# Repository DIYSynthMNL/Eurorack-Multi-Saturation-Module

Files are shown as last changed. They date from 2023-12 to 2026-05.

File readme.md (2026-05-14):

# Synth Distortion / Saturation Module Design

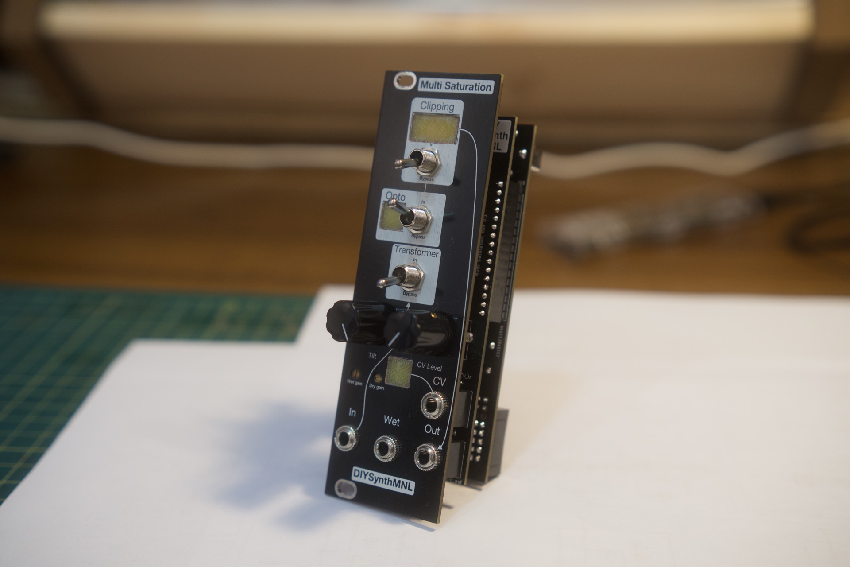
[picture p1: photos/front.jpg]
Multi Saturation assembled


## Revision Summary

- Schematic Revision 0.5 - an easier to read schematic - please note that there are some errors in this. The Eurorack power connector pins are backwards. Use this as a reference for the circuit design.
- Schematic Revision 0.6 - multiboard layout (LATEST - working on circuit revisions)
- PCB Revision 0.1 - revising in progress (working on rev 0.2)

## Some background.

I’m designing a distortion/saturation modular synth module using different methods of distorting audio signals.

This module is a combination of transformer, opto, and clipping distortion/saturation.

## Source of inspiration

Local archived copies of the borrowed-source schematics live in [`references/`](references/) so this repo stays useful if the upstream links die. Originals from [diyrecordingequipment.com](https://www.diyrecordingequipment.com/pages/the-colour-format).

- **CTX Cinemag Transformer Colour mkII** — [local copy](references/DIYRE-CTX-Cinemag-mkII-schematic.pdf) · [upstream](https://cdn.shopify.com/s/files/1/0698/2265/files/CTX_mkII_Schematic.pdf?375)
- **Colourphone (v1.3)** — [local copy](references/DIYRE-Colourphone-schematic-v1.3.pdf) · [upstream](https://cdn.shopify.com/s/files/1/0698/2265/files/XQP_Colourphone_Schematic_1.3.pdf?8973696934571457842)
- **Colourupter (v1.7)** — [local copy](references/DIYRE-Colourupter-schematic-v1.7.pdf) · [upstream](https://cdn.shopify.com/s/files/1/0698/2265/files/XQP_Colourupter_Schematic_1.7.pdf?13355729951948932441)

### DIYRe’s Colour Modules

I got some ideas from DIYRe's Colour modules. DIYRe is a company that produces DIY kits for professional audio recording equipment. Some of their product offerings include recording studio rackmount effects.

[The Colour Format](https://www.diyrecordingequipment.com/pages/the-colour-format)

| Colour Module | What does it do? | What ideas did you get? | Link to page | Schematic |
| --- | --- | --- | --- | --- |
| CTX Transformer Colour | A transformer saturation module with a discrete opamp and a Cinemag audio transformer which has a 1:1 turns ratio. | Non-inverting amp to drive the transformer past what it can handle. Resistor before the transformer that isolates the opamp from the transformer. | https://www.diyrecordingequipment.com/products/ctx-cinemag-transformer-colour-mkii | https://cdn.shopify.com/s/files/1/0698/2265/files/CTX_mkII_Schematic.pdf?375 |
| Colourphone | A telephone sound emulator. It uses a bandpass filter and a 1:1 turn ratio audio transformer. | I have a similar transformer which is a 600:600 ohm transformer. Resistor before the transformer that isolates it from the opamp. | https://www.diyrecordingequipment.com/products/colourphone-telephone-distortion-colour | https://cdn.shopify.com/s/files/1/0698/2265/files/XQP_Colourphone_Schematic_1.3.pdf?8973696934571457842 |
| Colourupter | An opto distortion module that is vactrol based. | Using a vactrol and the circuit around it. IC1c and IC1d only. | https://www.diyrecordingequipment.com/products/colourupter | https://cdn.shopify.com/s/files/1/0698/2265/files/XQP_Colourupter_Schematic_1.7.pdf?13355729951948932441 |

### Other sources

- Vactrol wet/dry mix from music thing modular’s spring reverb module
    - [https://www.musicthing.co.uk/Spring-Reverb/](https://www.musicthing.co.uk/Spring-Reverb/)
- Eliot Sound Products [https://sound-au.com](https://sound-au.com/) - is a website full of audio articles that I’ve learned from. Go search for these articles, they’re great!
    - Designing With Op Amps
    - Audio Transformers
    - Soft Clipping

# Circuit Design

- I will update this section soon.

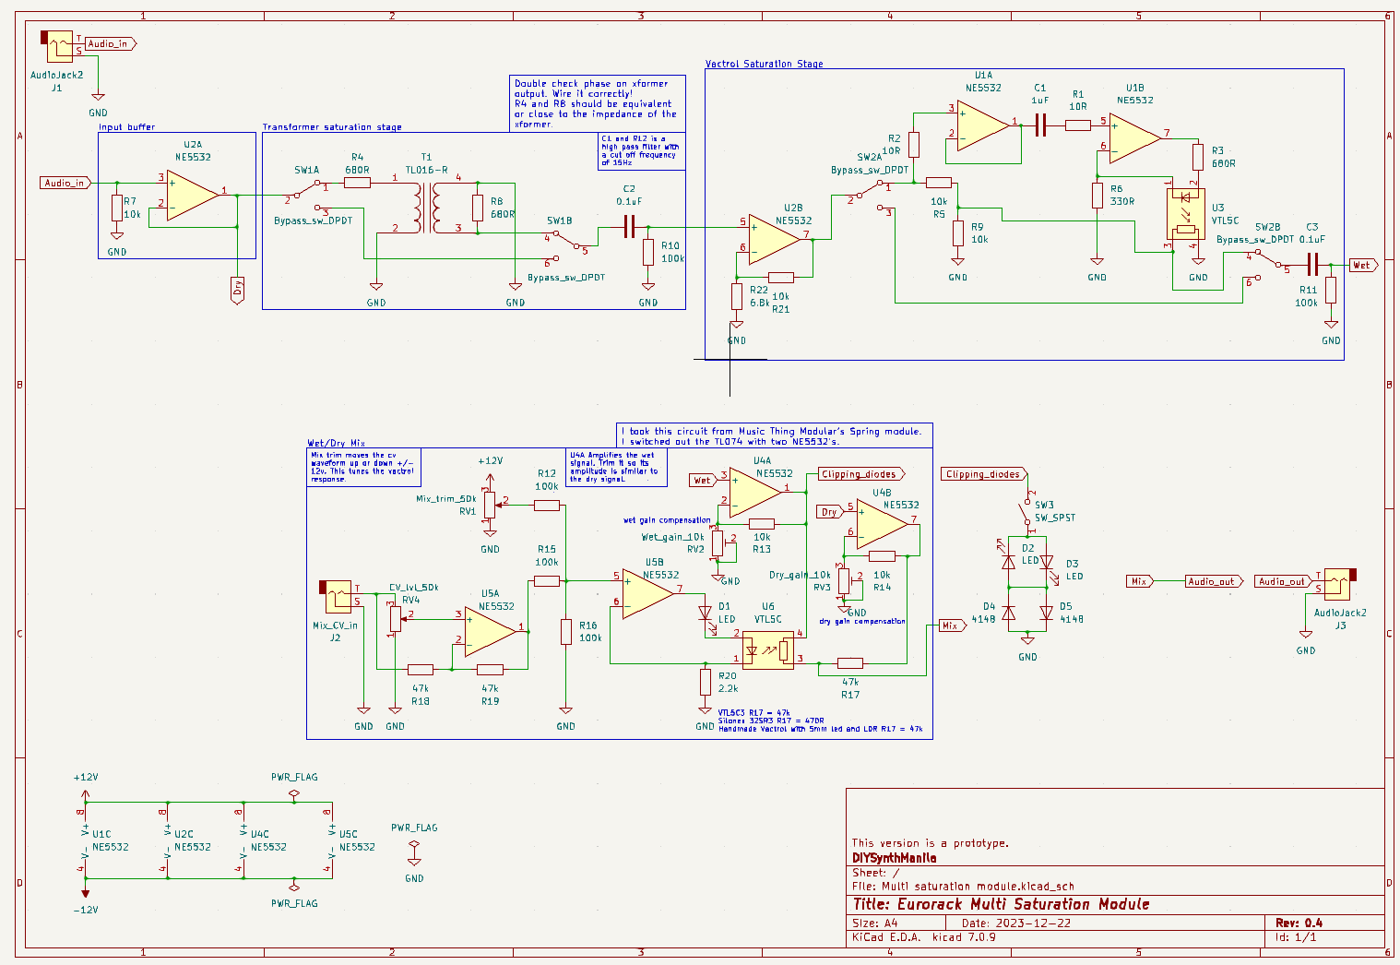
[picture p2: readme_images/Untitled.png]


### Stages

1. Input gain stage (buffer only, see design note below)
    
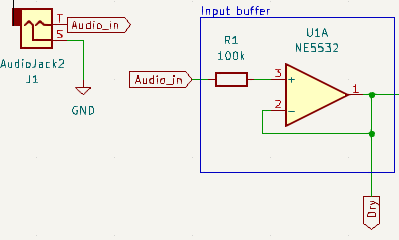
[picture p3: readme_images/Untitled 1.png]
    
    
    We must take into account the headroom of the op amp. The NE5532 can only output 2 volts less than the supply voltage. So for example, your supply voltage would be +/- 12V, your max output would be 10V based on the image below.
    
    
    
    A buffer would suffice as the input stage. It would be nice to give the transformer more voltage but we wouldn’t be able to amplify the 10Vpp input to 12Vpp unless we use a +/- 15V supply. 
    
    I chose to use an NE5532 Op Amp because I believe it can drive outputs higher than TL07x.
    
2. Transformer Saturation
    
    The transformer distortion works by oversaturating the transformer’s core past what it can handle. The transformer I used would normally be used in line audio signals. A 600:600 ohm transformer. We’re using Eurorack voltage which is around 10vpp so that would oversaturate the transformer.
    
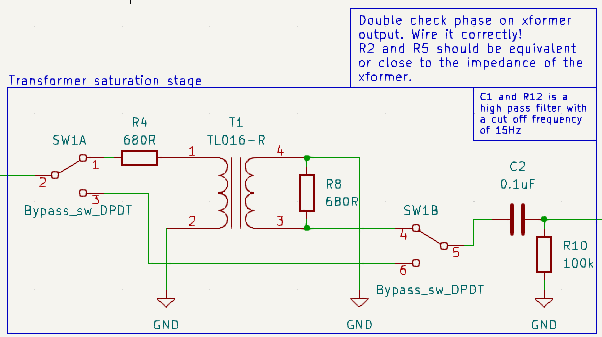
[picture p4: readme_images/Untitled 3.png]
    
    
3. Vactrol Opto Electronic Saturation
    
    The transformer’s output was low, I needed to add a non-inverting op amp with gain to bring the levels back to 10vpp for this stage.
    
    I got this circuit from DIYRe’s Colourupter colour module which uses a Vactrol to clip the signal.
    
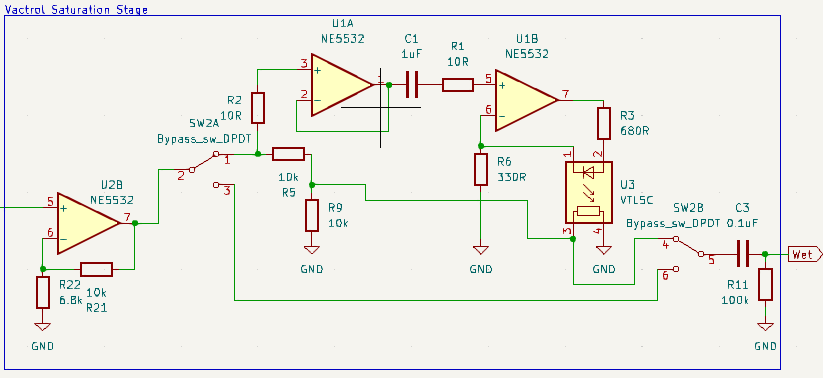
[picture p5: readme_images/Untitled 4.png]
    
    
4. Soft Clipping Diode Saturation
    
    I chose to place these diodes after the wet amplifier. It would be softer if I placed it before the U4A. I chained LEDs to the 1N4148s to get a softer clipping effect. LEDs alone would make saw waves looking like square waves.
    
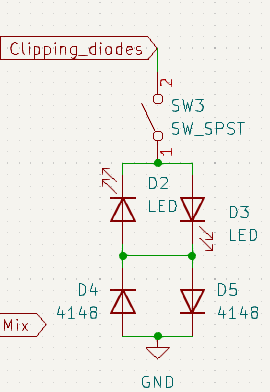
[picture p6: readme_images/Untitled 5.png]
    
    
5. Voltage controlled Vactrol Wet/Dry mix
    
    I used my handmade Vactrol. I made it using a 5mm diffused red LED and a 5mm LDR enclosed with black heat shrink tubing. I crimped the ends so no light would leak in. 47k works for R17 with my Vactrol.
    
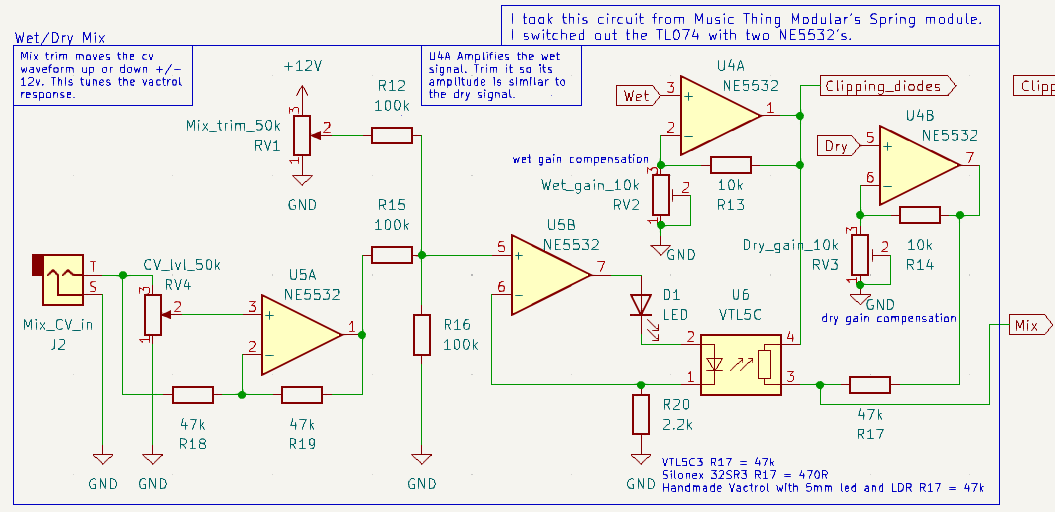
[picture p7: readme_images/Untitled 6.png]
    

## Schematic Revisions:

- Revision 0.2
    - TODO
        - [x]  Replace R5 with trimmer
        - [x]  Test wet/dry mix on breadboard
        - [x]  Input buffer biasing resistor
    - Notes
        - The transformer saturation is very subtle on a mono synth
- Revision 0.3
    - TODO
    - [x]  Add gain trimmer to dry signal at U2B
    - [x]  Scrap the single saturation and add diode clipping and the Colourupter, the transformer alone is too subtle
    - [x]  Test output gain stage
- Revision 0.4
    - [x]  Scrap output auto gain
    - [x]  add opto saturation
    - [x]  add soft clipping diodes
- Revision 0.5
    - [x]  Multiboard layout
- Revision 0.6
    - [ ]  Fix amplitude difference on opto sat stage output.

# PCB Design

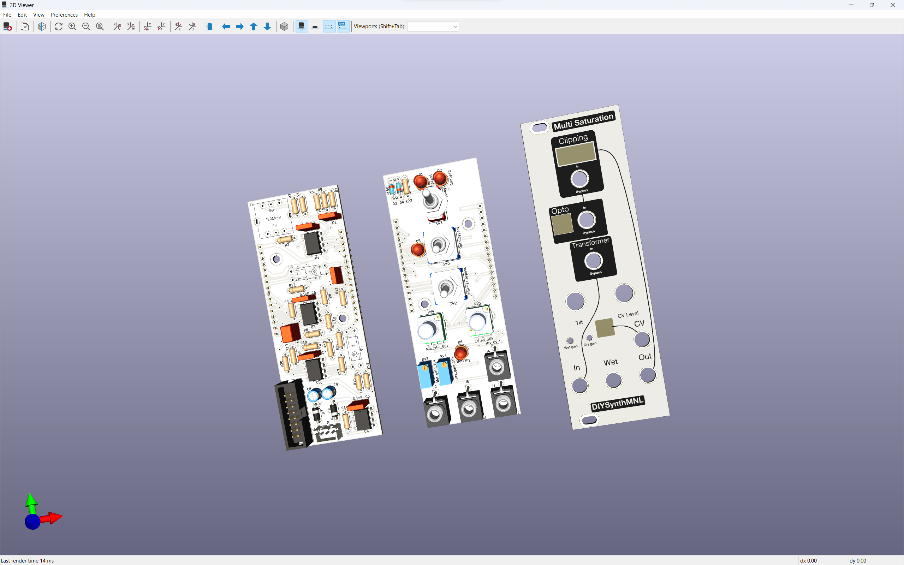
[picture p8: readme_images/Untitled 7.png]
Dec 27, 2023 - Almost satisfied with the board design, rev0.1


Dec 27, 2023 - Almost satisfied  with the board design, rev0.1

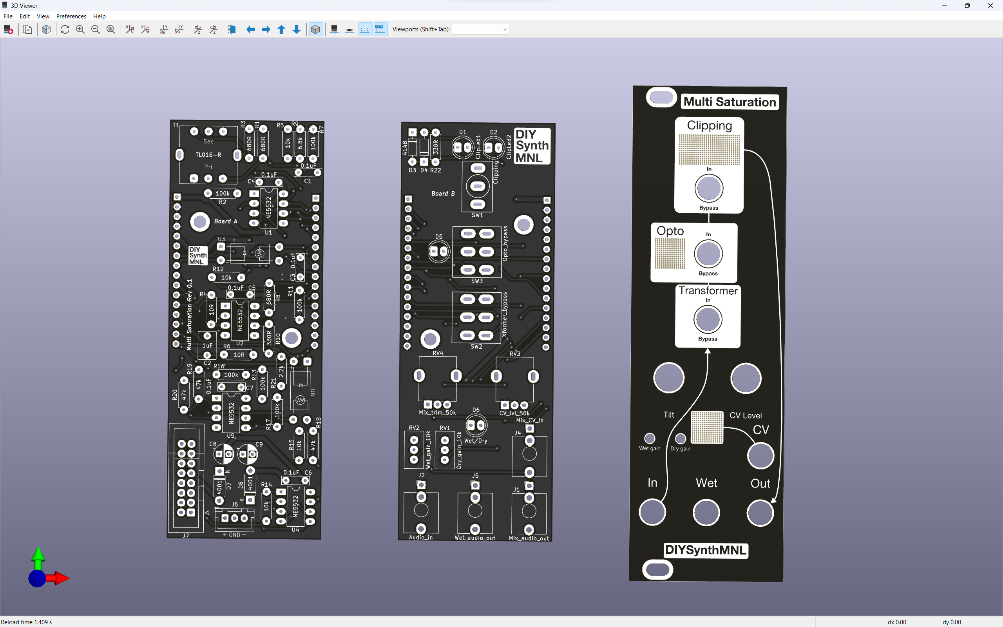
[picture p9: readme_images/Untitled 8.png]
Rev 0.1 in black


Rev 0.1 in black

## PCB revisions:

- Todo for Revision 0.1
    - [x]  Ground plane vias
    - [x]  Front panel ground plane
    - [x]  Double check hole sizes
        - [x]  Trimmer
    - [x]  Double check via sizes
    - [x]  Round tracks
- Todo for Revision 0.2
    - Front panel
        - [x]  Add keep out zone for led window zone fills for FCU and BCU - I had to Dremel it out for the revision 0.1 front panel board
        - [x]  Enlarge switch holes for Dailywell switches
        - [x]  Enlarge trimmer holes
        - [x]  Change tilt knob silkscreen to “mix”
        - [ ]  Fix amplitude difference on opto sat output. The opto stage attenuates the signal from the transformer too much
- Revision 0.1 Board test notes
    - Voltage tests
        - Power rails after reverse protection diode I used a 1N4007 diode
            - V+ reads about 10V
            - V- reads about 11V
            - I might need to change the reverse protection diodes to Schottkys
    - Music thing modular’s cv wet dry circuit has an optimal input of 0-5V control voltages. If 10Vpp was used, the middle of the cv level pot is zero. Fully clockwise, the cv would be in phase. Fully counter clockwise, the cv is inverted. This is simulated in falstad, the file is included in the falstad folder.
    - Gain trim is finicky. Turning on the Opto would attenuate the signal. Maybe this is caused by the variety of the vactrol, I think not all vactrols are equal. Opto gain/amplitude trim might be required. It might be a simple resistor value change within the circuit.
    - LEDs are not as bright as I want them.

## Circuit walkthrough

Three saturation stages in series, each individually bypassable from the front panel, then a CV-controlled wet/dry mix:

```
Audio In ─► U1A buffer ─┬─► [Dry path → wet/dry mixer U4B]
                        │
                        └─► SW1 (Xformer bypass) ─► [TL016 transformer, 680Ω matching, HPF 15Hz]
                                                  ─► U1B buffer ─► transformer-saturated signal
                                                                     │
                                                                     ▼
                                                  SW2 (Opto bypass) ─► U2A buffer ─► C2 (1µF) ─► U2B inverting amp (gain −68)
                                                                                                    ├─► drives U3 vactrol LED (R10 limits)
                                                                                                    └─► AC-coupled out as "Wet"
                                                                                                                                ▼
                                              U4A amp ────────► clipping LEDs + 1N4148 (SW1 on Board B bypasses)
   Dry signal ──► U4B amp ───────────────────┘                                                              │
                                                                                                            ▼
                                                                                  U6 vactrol (CV wet/dry mixer, driven by Mix CV via U5A/U5B)
                                                                                                            ▼
                                                                                                       Mix Audio Out
```

### Three saturation flavors, switchable

**1. Transformer saturation (TL016-R, 600:600Ω).** 680Ω resistors match the transformer's characteristic impedance. Driving the primary hard pushes the magnetic core into non-linearity — classic warm "tape-like" harmonic content (mostly odd harmonics). The 15Hz HPF (C1 + R7) on the secondary removes any DC bias.

**2. Opto-electronic saturation (vactrol, U3).** U2B is a high-gain inverting amp (R8/R6 = 680/10 = **−68× gain**) driving the vactrol's LED. As the signal gets louder, the LED brightens, the LDR resistance drops, more signal shunts to ground — soft compression / saturation. Fast attack/release due to the vactrol's photo response.

**3. Diode soft clipping (Board B).** LEDs (D1, D2) in series with 1N4148s (D3, D4) — asymmetric soft clipping with the LEDs adding ~2V of softness before the 4148s contribute hard clip. Pleasant warmth without harsh square-wave look. SW1 on Board B bypasses.

### Wet/Dry mix (CV-controlled)

Borrowed from Music Thing Modular's Spring reverb topology. Second vactrol (U6) acts as a CV-controlled variable resistor in the mix path. Mix CV input → U5A → U5B → vactrol LED. The Mix Trim pot (RV4, 50K) shifts the CV center point by ±12V so the vactrol's response curve aligns with your CV source (the Music Thing original optimizes for 0–5V CV; this tuning lets it handle ±5V or other ranges).

### Calibration

Three trim pots accessible from the front panel:

**RV2 — Wet gain trim.** Sets U4A's amplification of the wet (saturated) signal. Goal: match the wet signal's amplitude to the dry signal so the mix knob crossfades cleanly.

**RV3 — Dry gain trim.** Sets U4B's amplification of the dry signal. Adjust together with RV2 until at the mix midpoint, the output amplitude doesn't jump as you switch saturation stages on/off.

**RV4 — Mix trim.** Shifts the Mix CV bias up or down ±12V. Adjust until the panel mix pot's full clockwise position gives 100% wet and full counter-clockwise gives 100% dry, with your CV source connected. With no CV connected (or 0V), midpoint should give 50/50.

Procedure:
1. Patch a steady audio signal (e.g., a sawtooth from a VCO) into Audio In.
2. Set all bypass switches to "off" (no saturation) — only the dry path is active.
3. Patch a scope on Mix Audio Out. Note the amplitude.
4. Switch in transformer saturation (SW1). Adjust RV2 (wet gain) so the amplitude is similar to dry.
5. Switch in opto saturation (SW2). If the amplitude drops dramatically here, see [issue #1](https://github.com/DIYSynthMNL/Eurorack-Multi-Saturation-Module/issues) for the known opto-sat fix.
6. With a 0–5V LFO into Mix CV, adjust RV4 (mix trim) so panel mix pot fully clockwise = wet, fully counter-clockwise = dry.

## Build status

What's ready for builders today, and what's still on the TODO list:

**Production assets** (what you need to actually fabricate and assemble a final unit)

- [x] Schematic — Rev 0.6 ([Single saturation module - Multiboard Schematic - rev0.6.pdf](Schematic%20PDFs/Single%20saturation%20module%20-%20Multiboard%20Schematic%20-%20rev0.6.pdf))
- [x] PCB layout — rev 0.1 separated for fab in `kicad/Separate boards/rev 0.1/`; rev 0.2 fixes pending (see PCB revisions in readme)
- [ ] Gerber files for fabrication — none yet
- [x] BOM — [ibom.html](BOMs/ibom.html)
- [x] Final front panel (SVG/PDF for fab) — [MultiSaturation_FPANEL_FOR_KICAD_IMPORT.svg](Front%20panel%20graphics/MultiSaturation_FPANEL_FOR_KICAD_IMPORT.svg)
- [x] License — [LICENSE](LICENSE)

**Prototype assets** (for breadboard / perfboard / 3D-printed-panel builds before final PCB)

- [ ] 3D-printed prototype panel STL — none yet

**Documentation**

- [x] Photos of the assembled module — see [photos/](photos/)
- [ ] Demo video — none yet
- [ ] Build / assembly instructions — none yet
- [ ] Calibration / tuning notes — none yet

Want to help fill a gap (build photos, gerbers, an assembly guide)? Open an issue or PR.

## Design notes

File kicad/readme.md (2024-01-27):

# Schematic and Boards
I use KiCad with the help of plugins to make it easier to have multi board stack modules.
## My workflow
Based on this workflow you would understand better the files that are in this folder.
- Create an initial schematic
- Create a multiboard schematic
- Design the boards in one file
- Separate the boards using the KiKit plugin
- Use the PCBWay plugin to automatically send the gerbers for PCB manufacturing

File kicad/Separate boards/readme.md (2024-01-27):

# Separate Boards
Within each pcb manufacturing revision, separate boards are made by using KiKit. Then gerbers are generated inside their respective folders. I used PCBWay and their KiCad plugin that generate gerbers while simultaneously ordering them online.

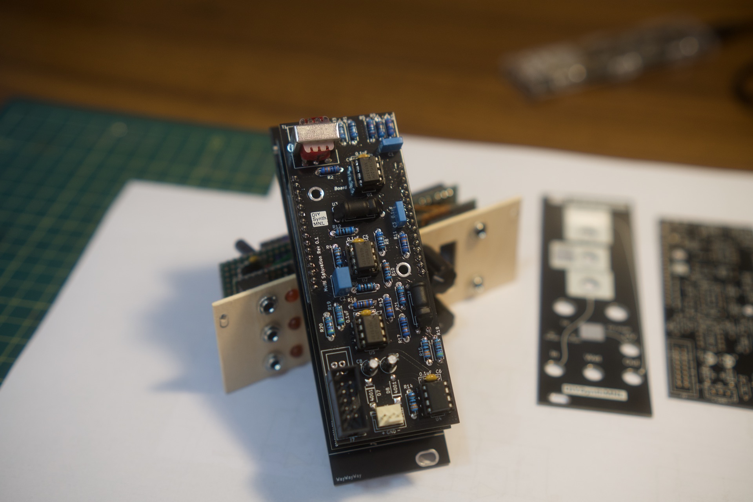
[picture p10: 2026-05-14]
photos/pcb-detail.jpg

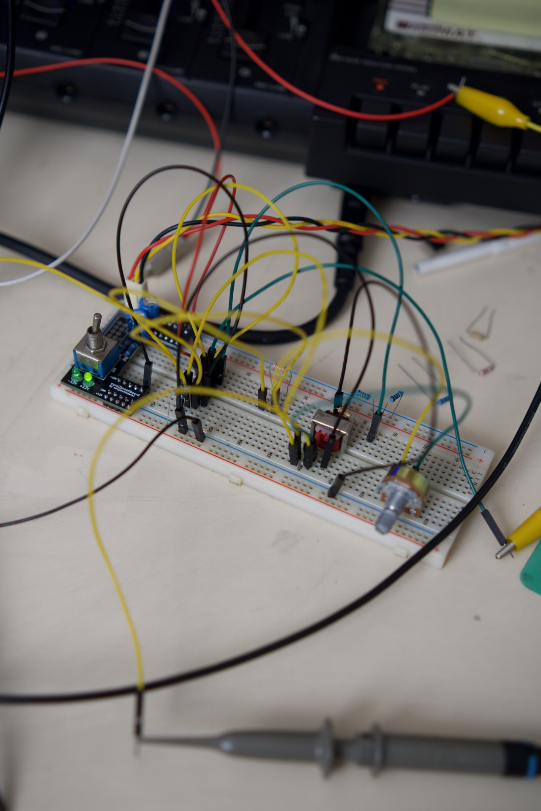
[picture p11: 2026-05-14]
photos/prototyping/proto-01.jpg

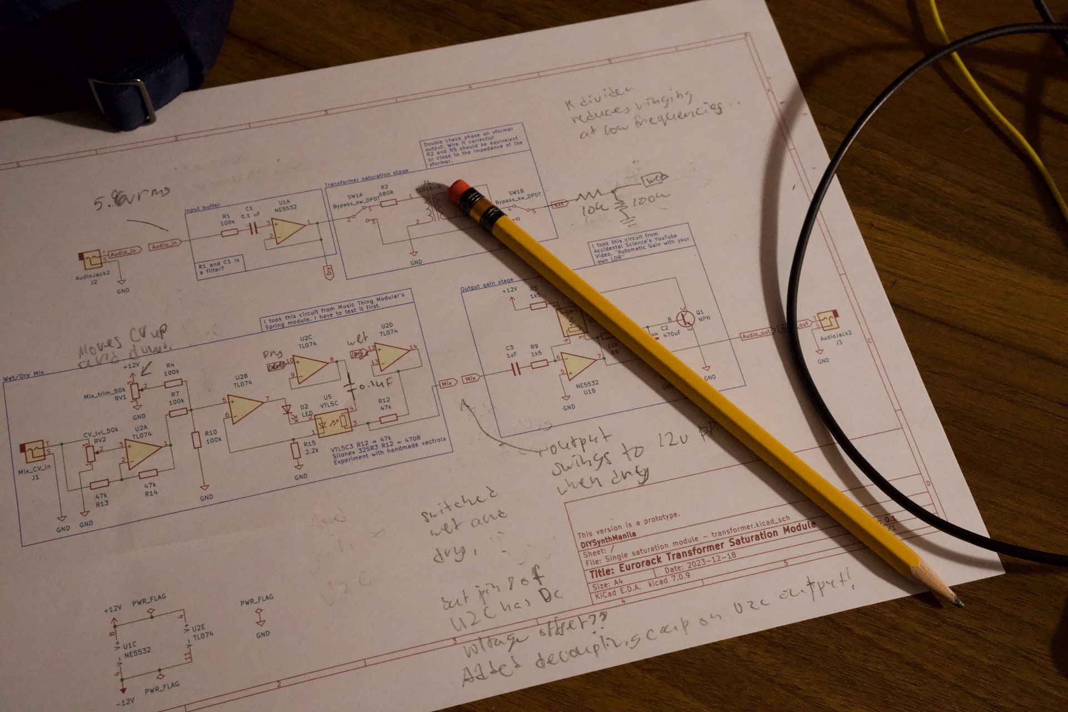
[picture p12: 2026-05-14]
photos/prototyping/proto-12.jpg

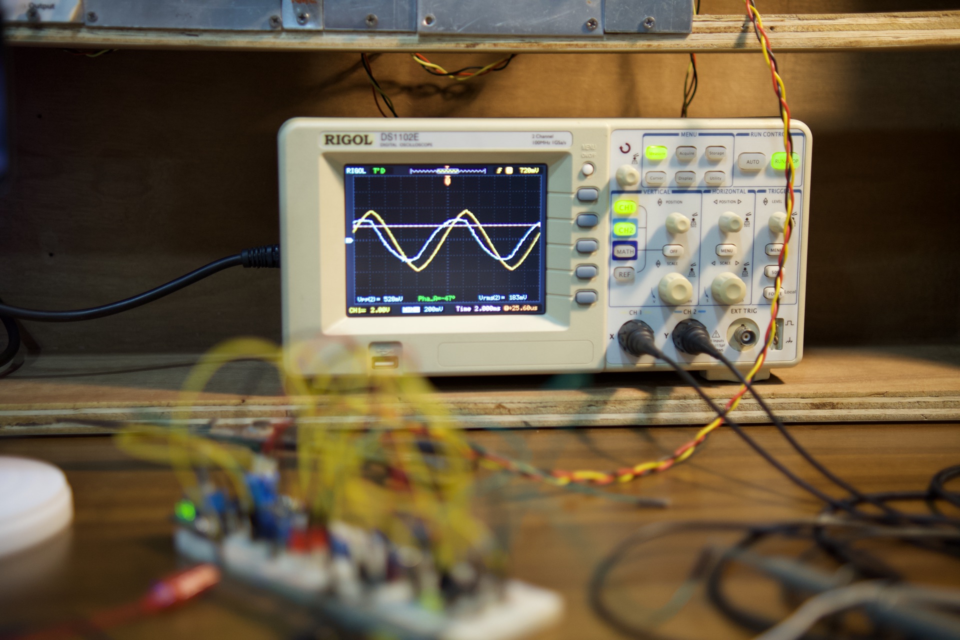
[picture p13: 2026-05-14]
photos/prototyping/proto-08.jpg

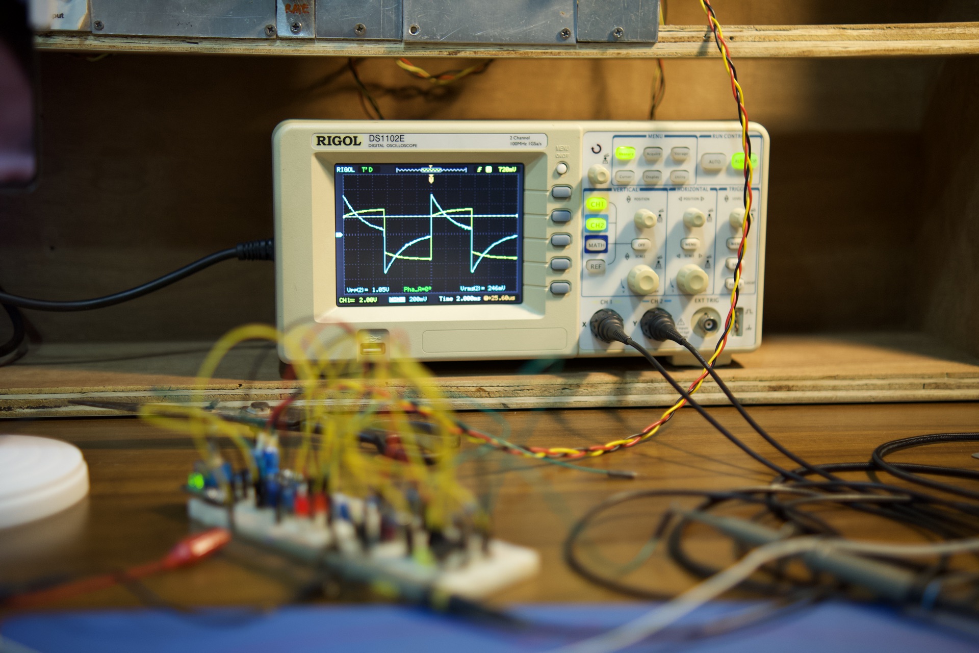
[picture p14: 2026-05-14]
photos/prototyping/proto-07.jpg

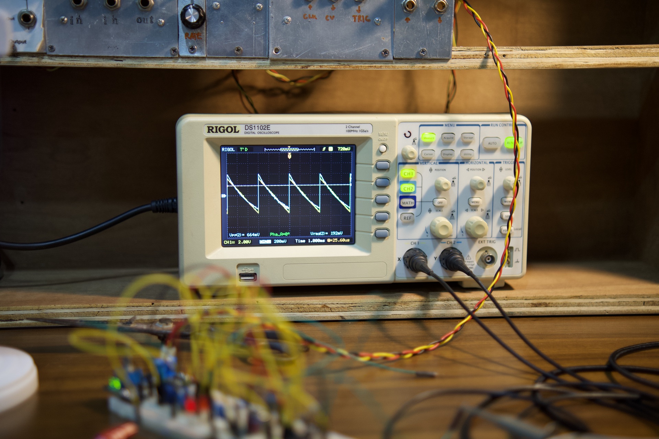
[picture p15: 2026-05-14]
photos/prototyping/proto-09.jpg

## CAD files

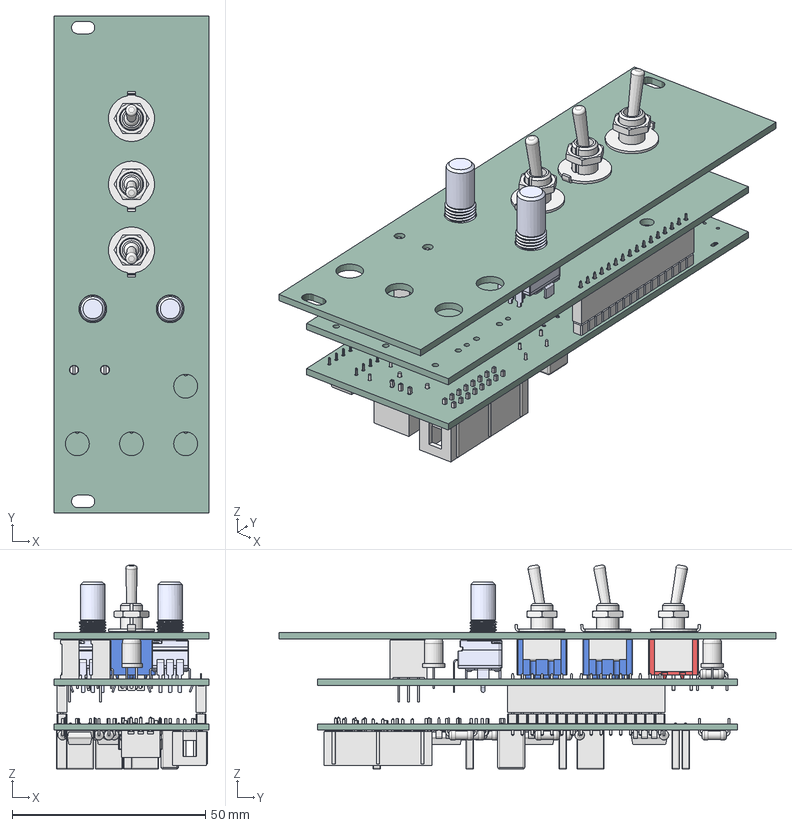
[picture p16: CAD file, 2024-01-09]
3D model/MultiSaturation_3D_Model.FCStd
40.0 x 128.5 x 52.7 mm
Multi saturation module PCB1
Multi saturation module PCB2
Multi saturation module PCB3

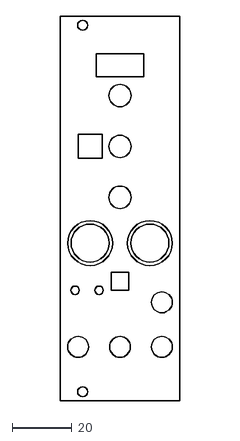
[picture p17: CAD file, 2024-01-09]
Front panel graphics/MultiSaturation_FPANEL.dxf
40.0 x 128.5

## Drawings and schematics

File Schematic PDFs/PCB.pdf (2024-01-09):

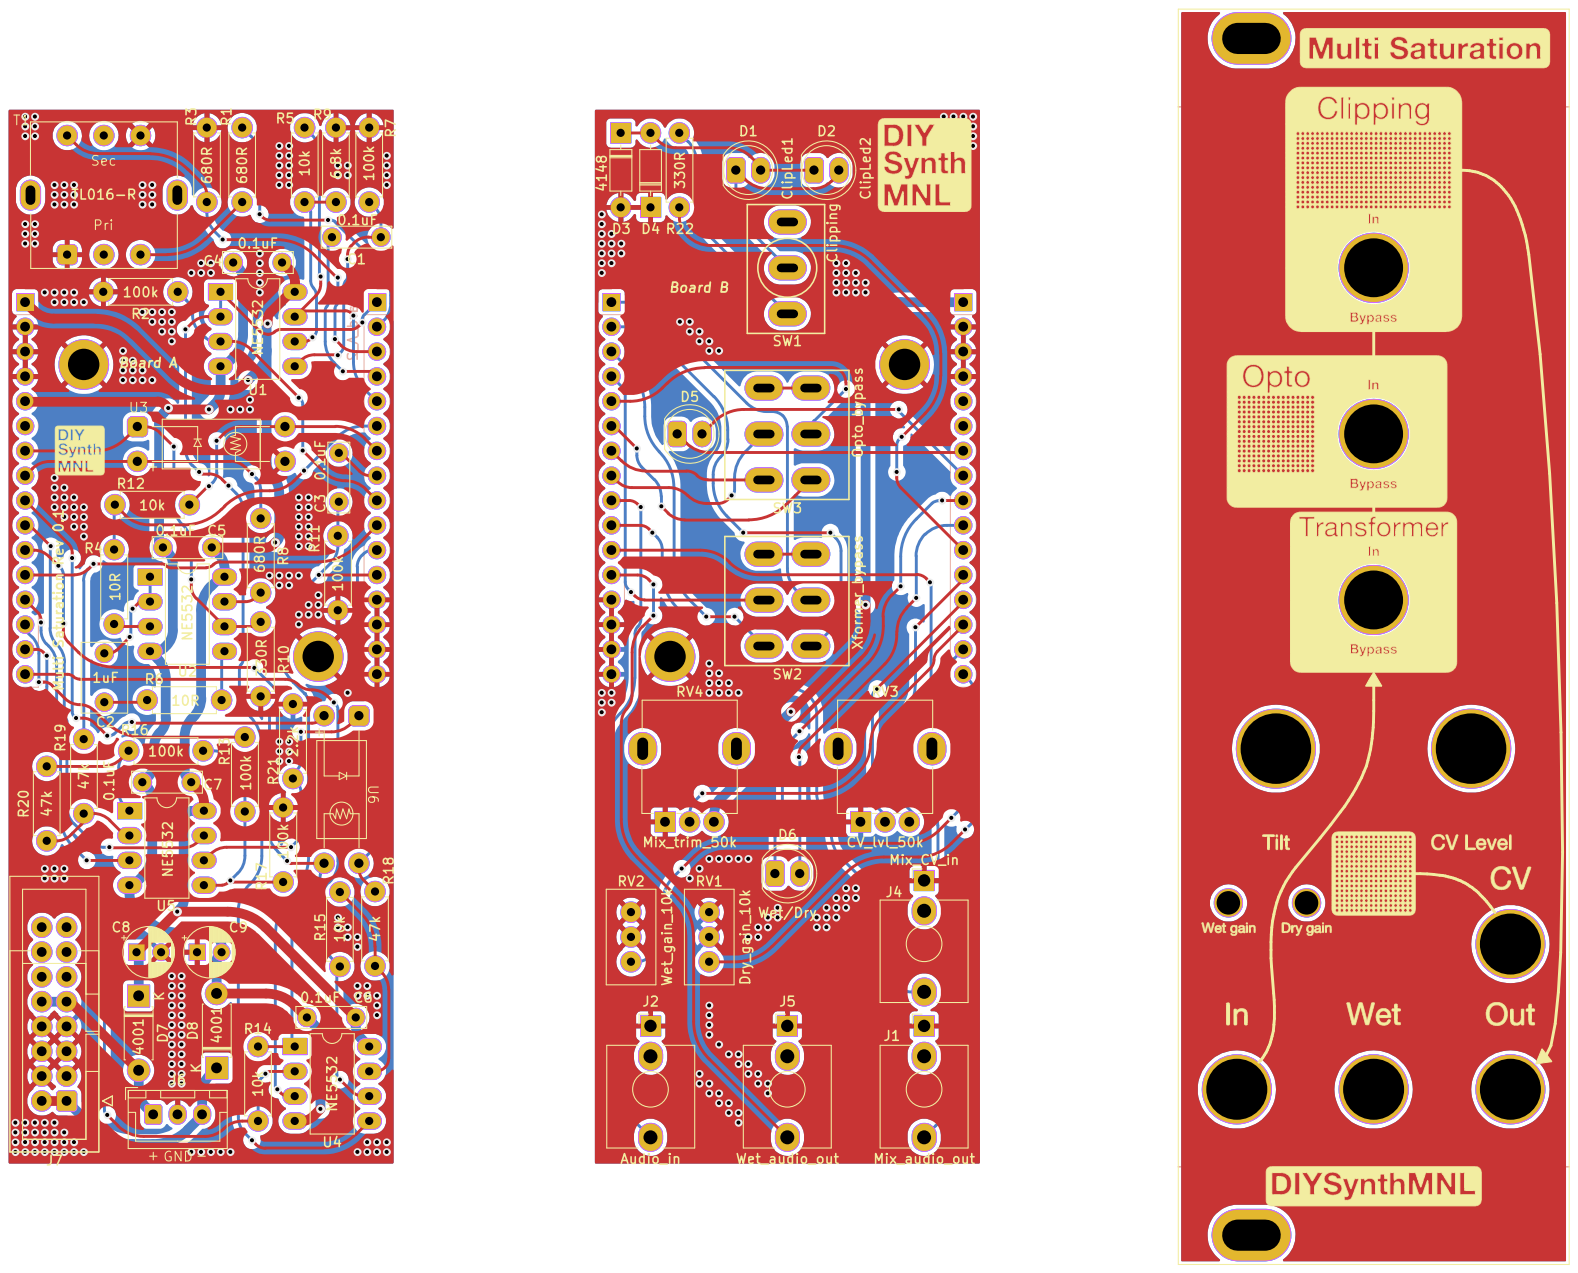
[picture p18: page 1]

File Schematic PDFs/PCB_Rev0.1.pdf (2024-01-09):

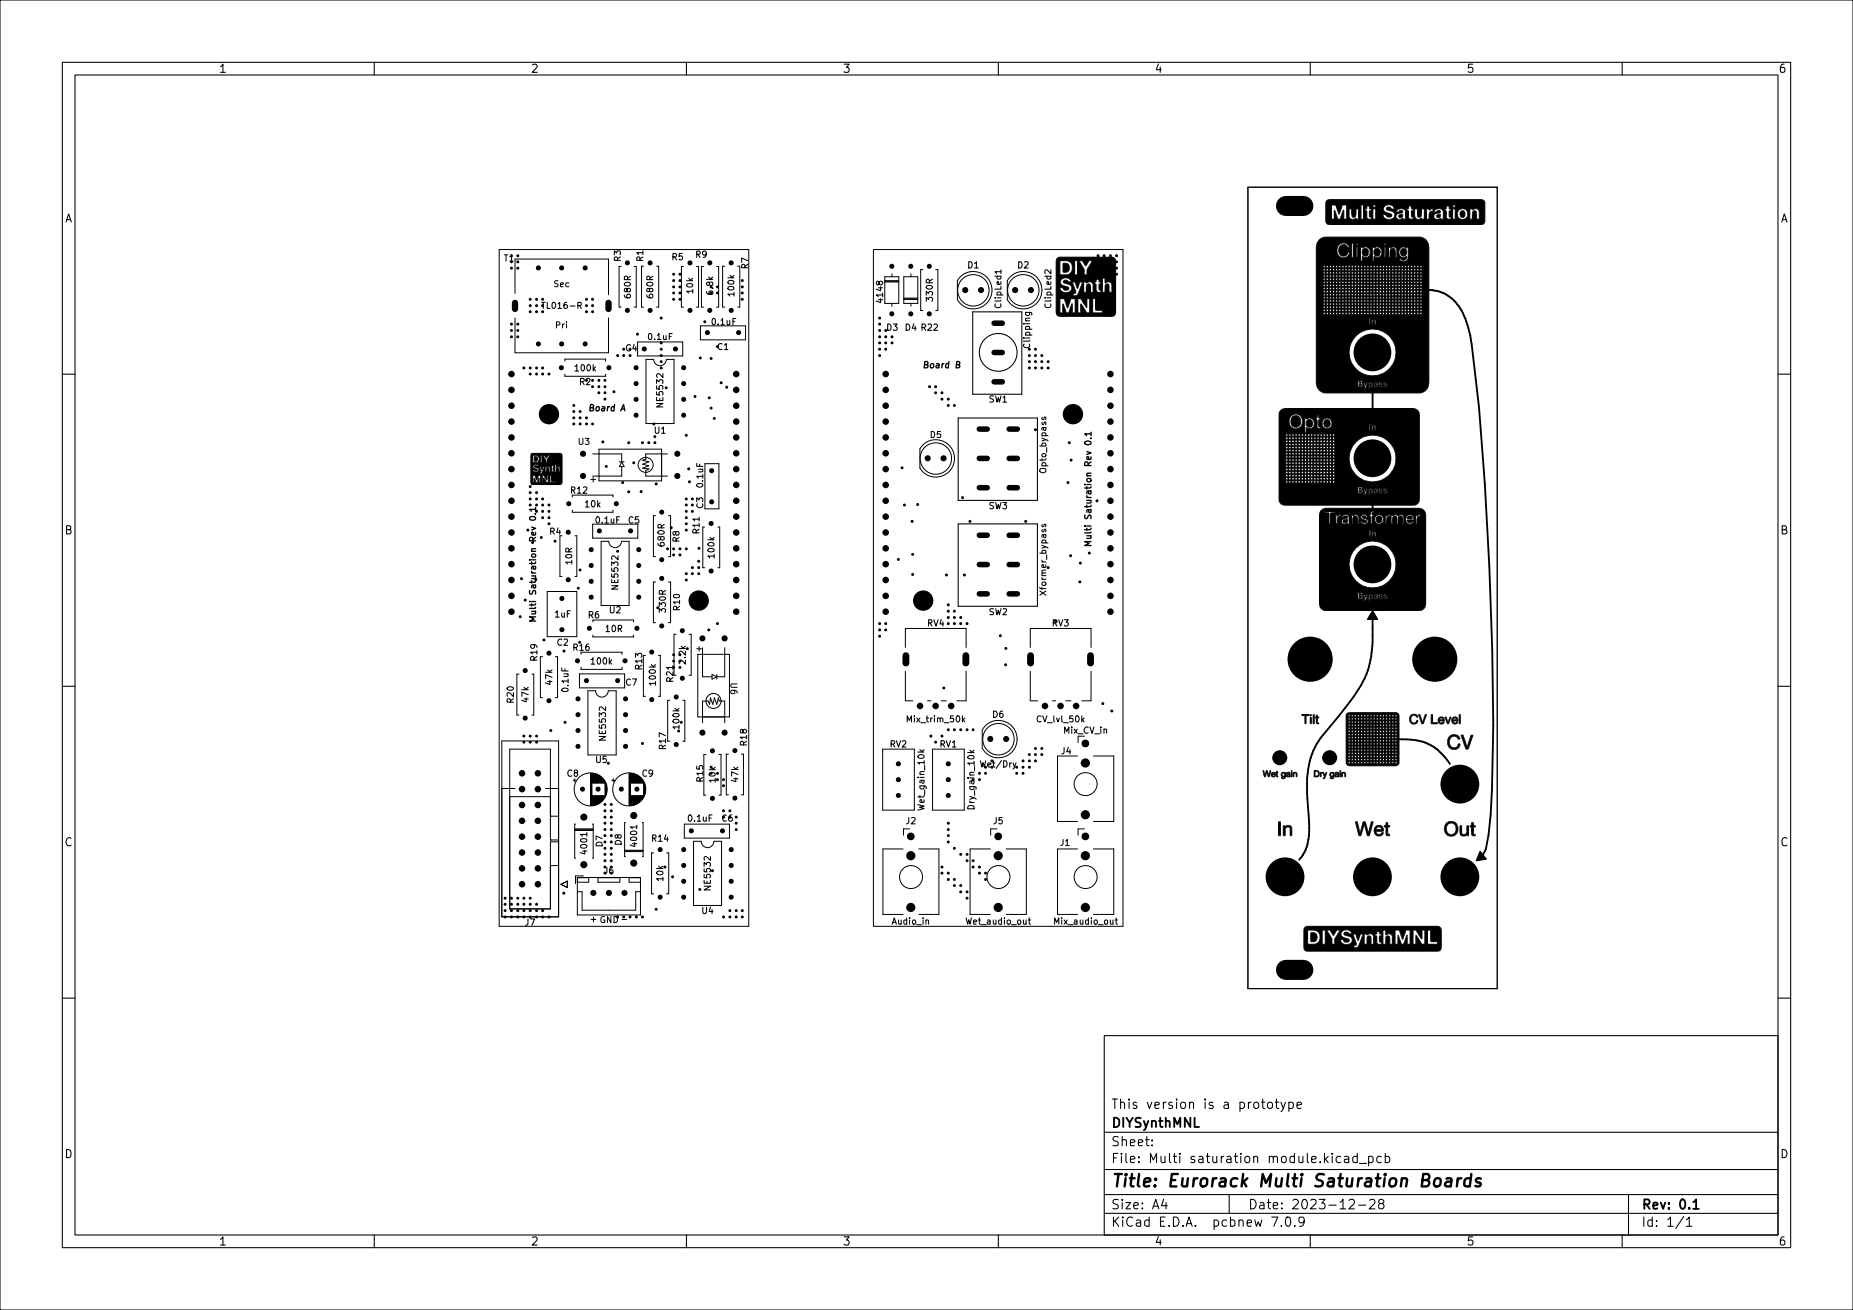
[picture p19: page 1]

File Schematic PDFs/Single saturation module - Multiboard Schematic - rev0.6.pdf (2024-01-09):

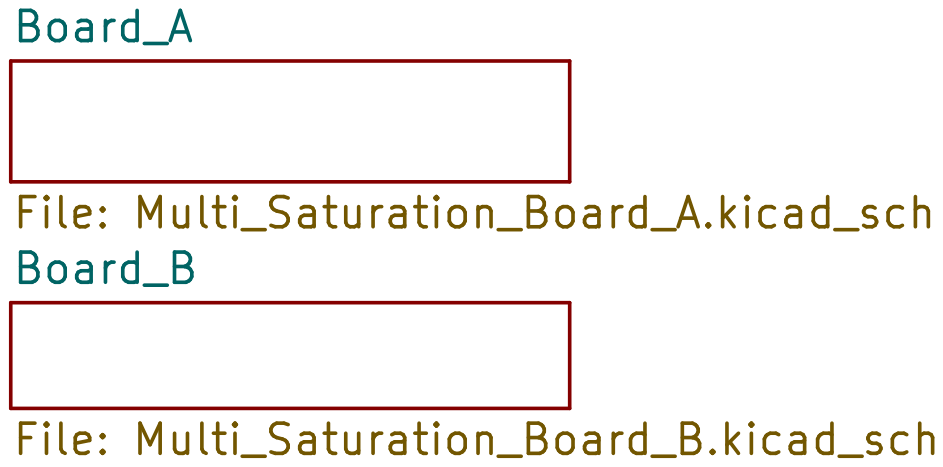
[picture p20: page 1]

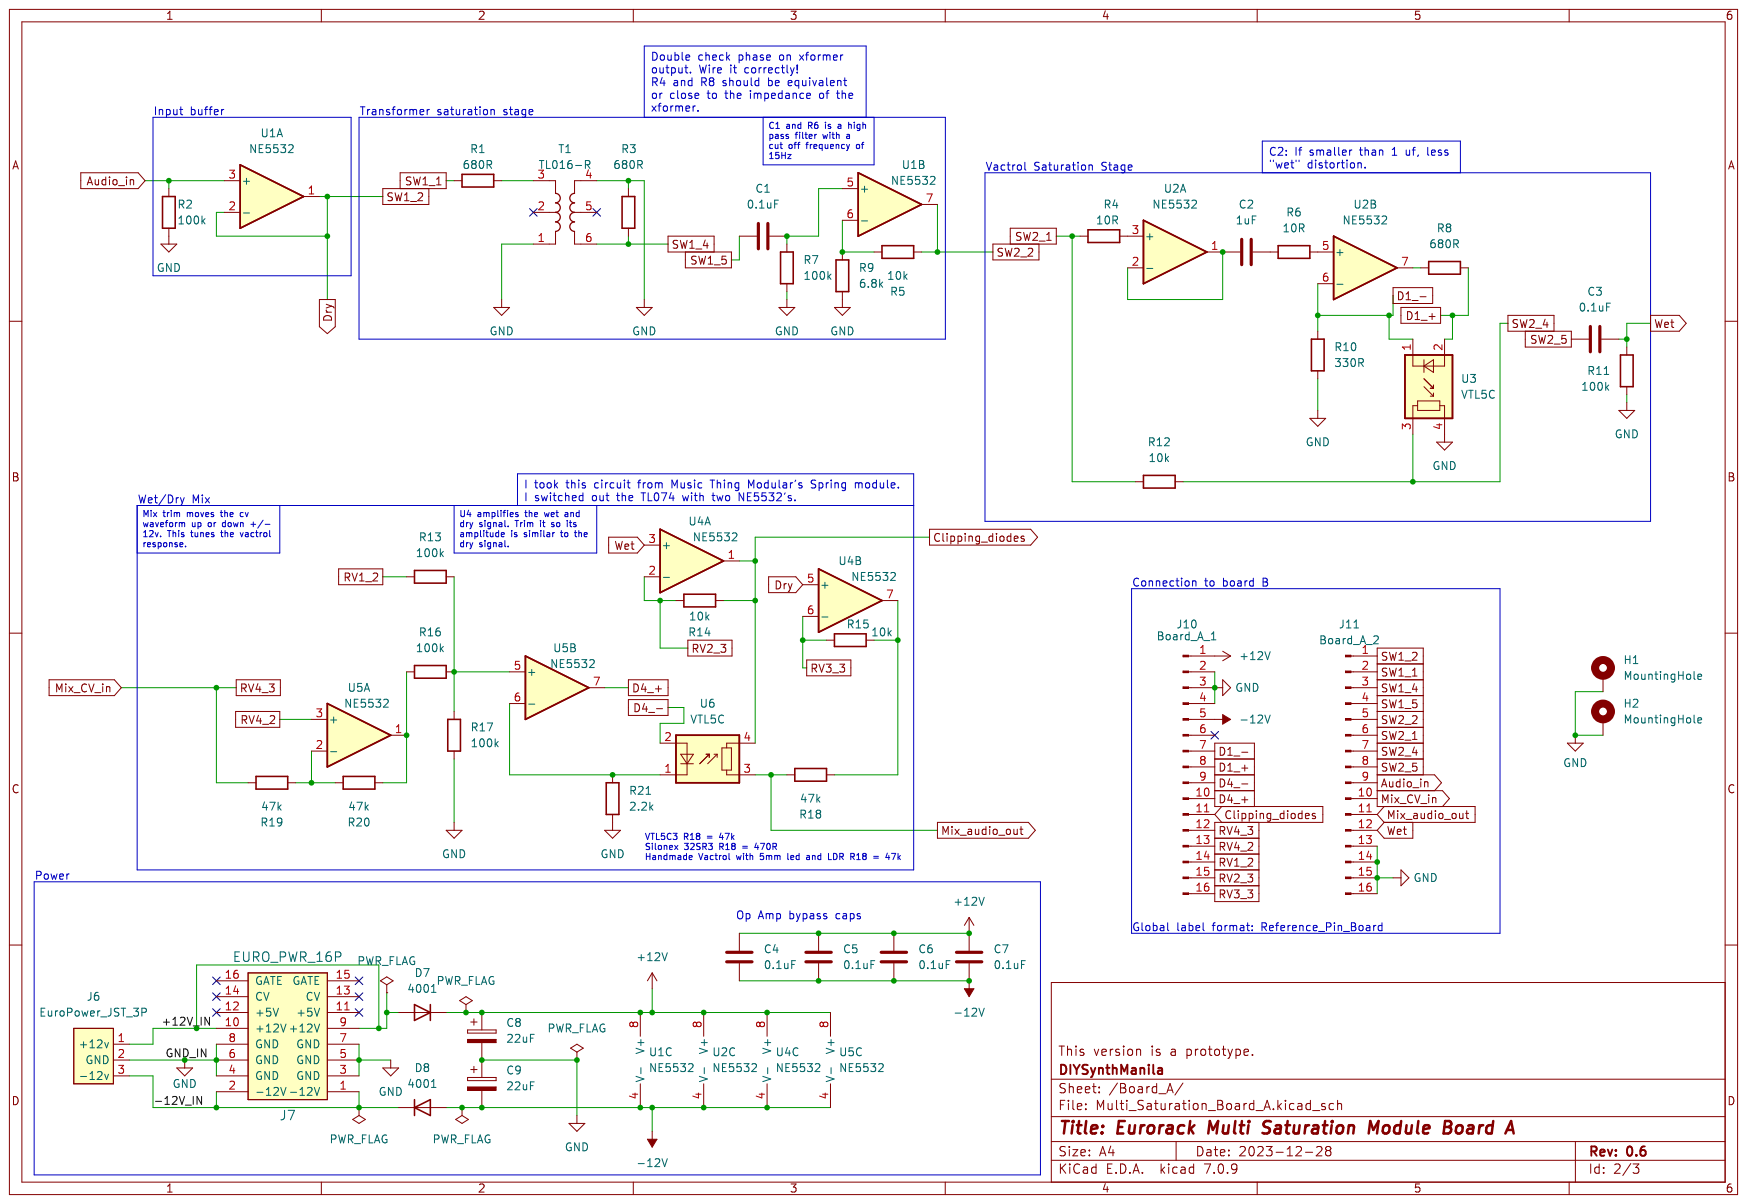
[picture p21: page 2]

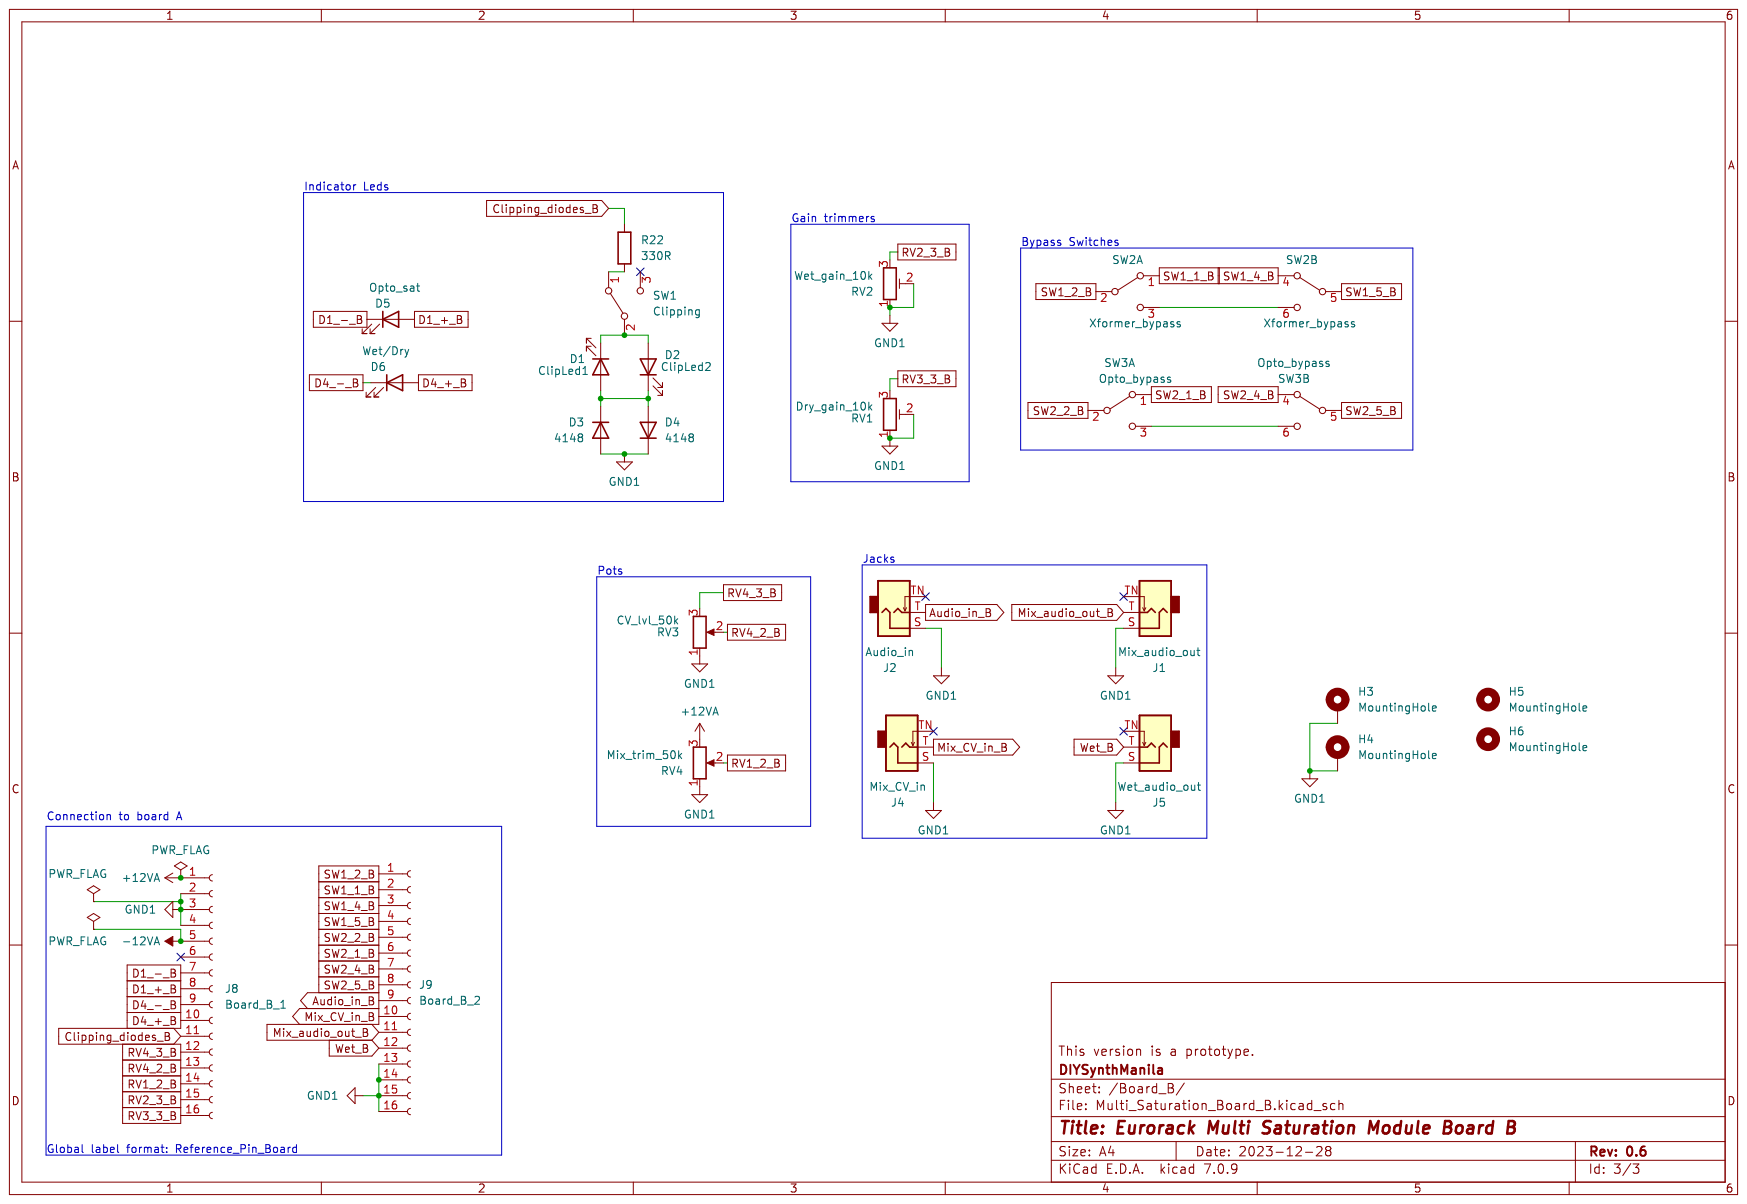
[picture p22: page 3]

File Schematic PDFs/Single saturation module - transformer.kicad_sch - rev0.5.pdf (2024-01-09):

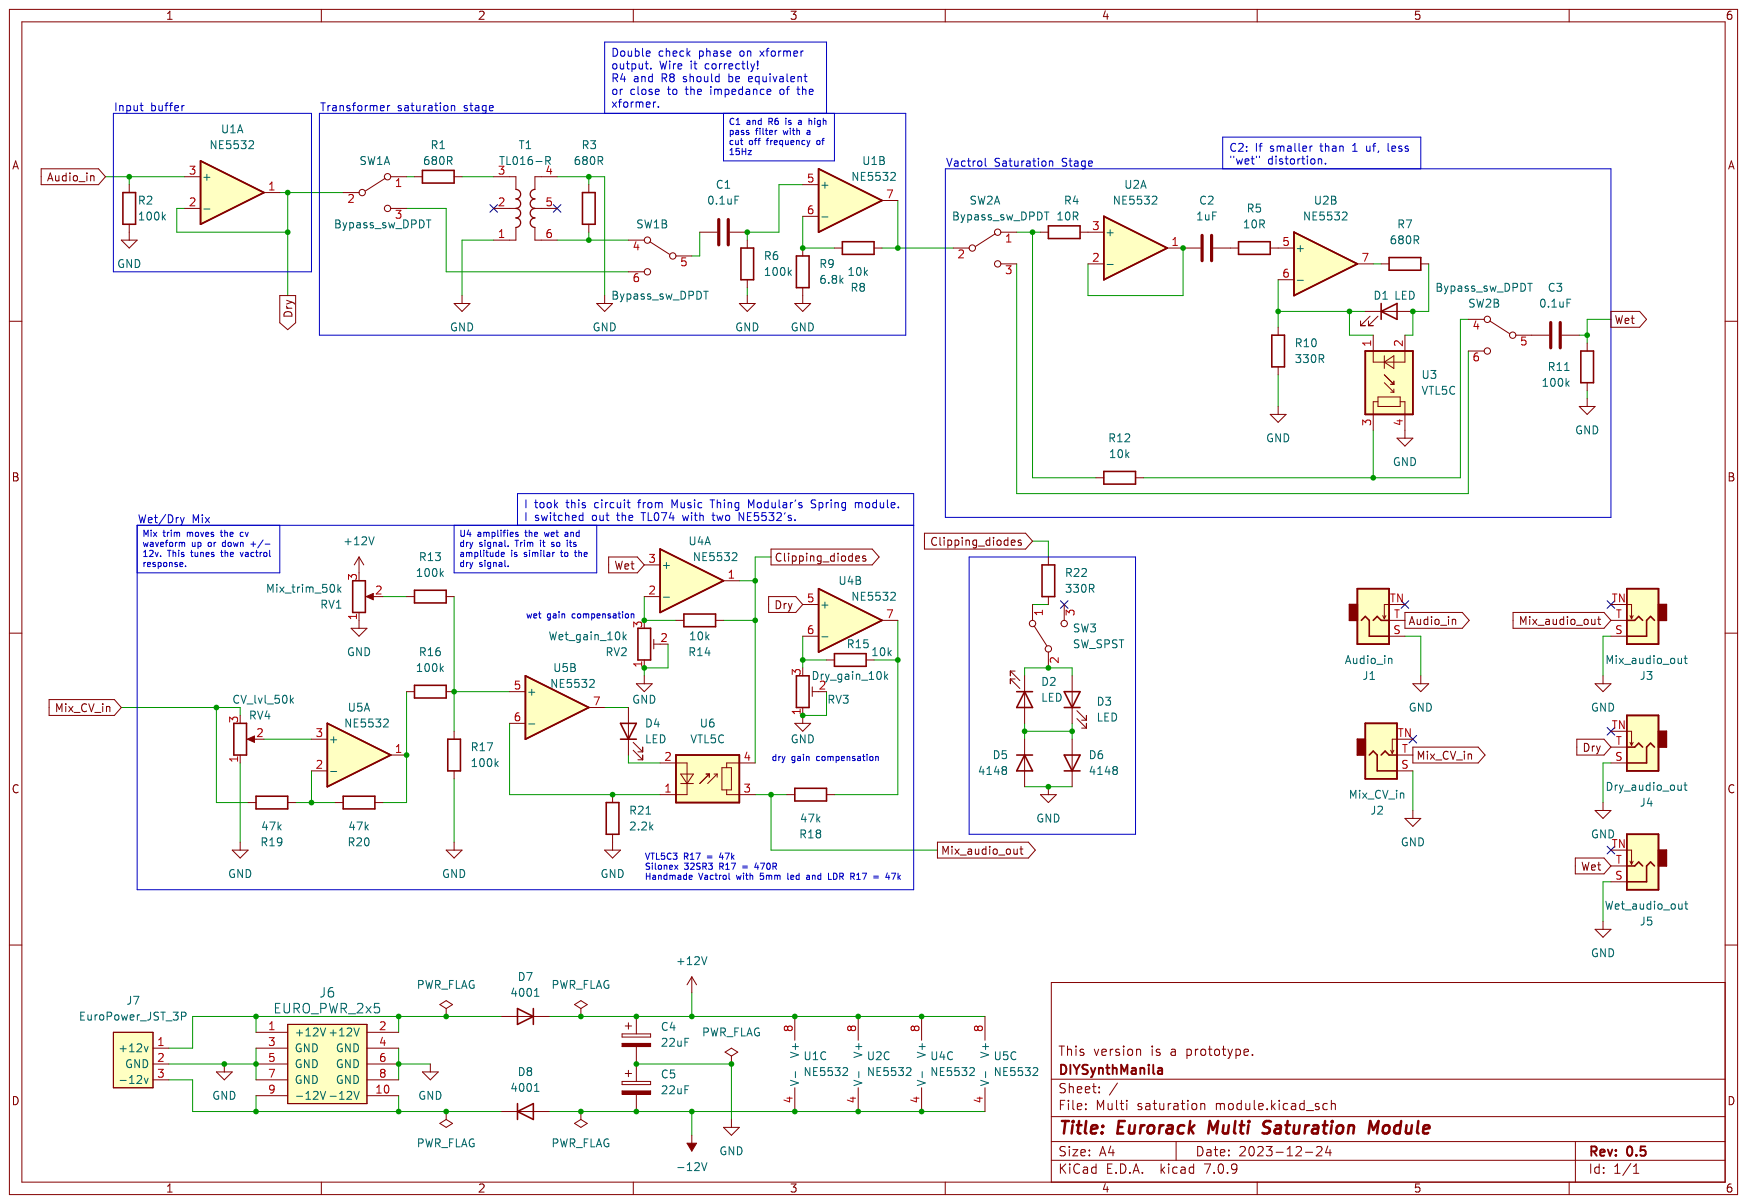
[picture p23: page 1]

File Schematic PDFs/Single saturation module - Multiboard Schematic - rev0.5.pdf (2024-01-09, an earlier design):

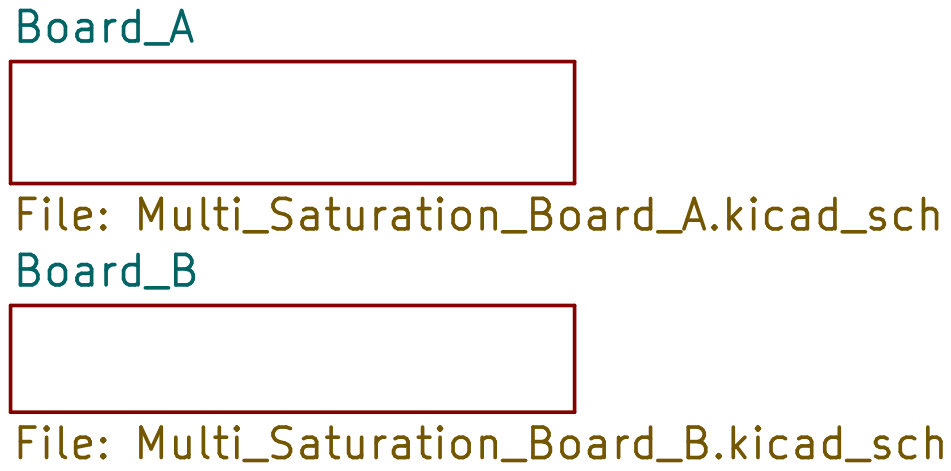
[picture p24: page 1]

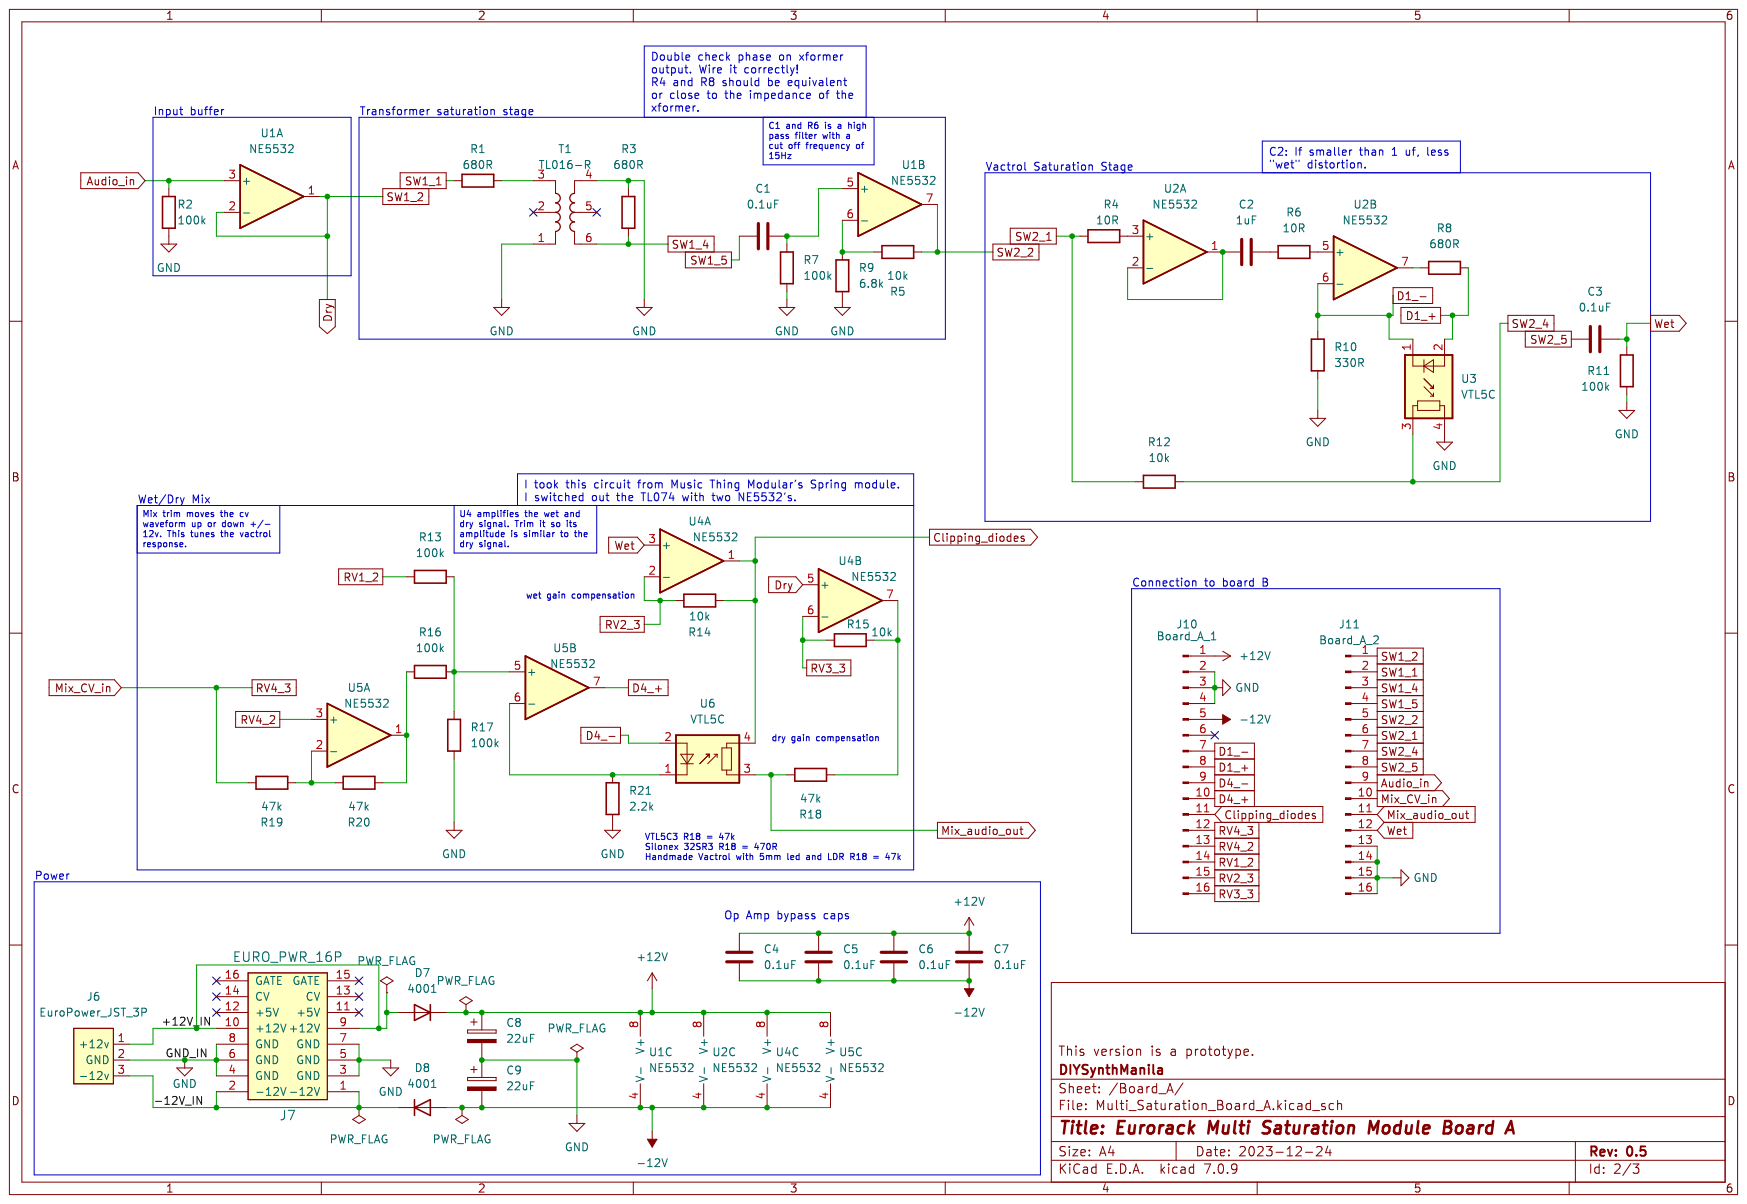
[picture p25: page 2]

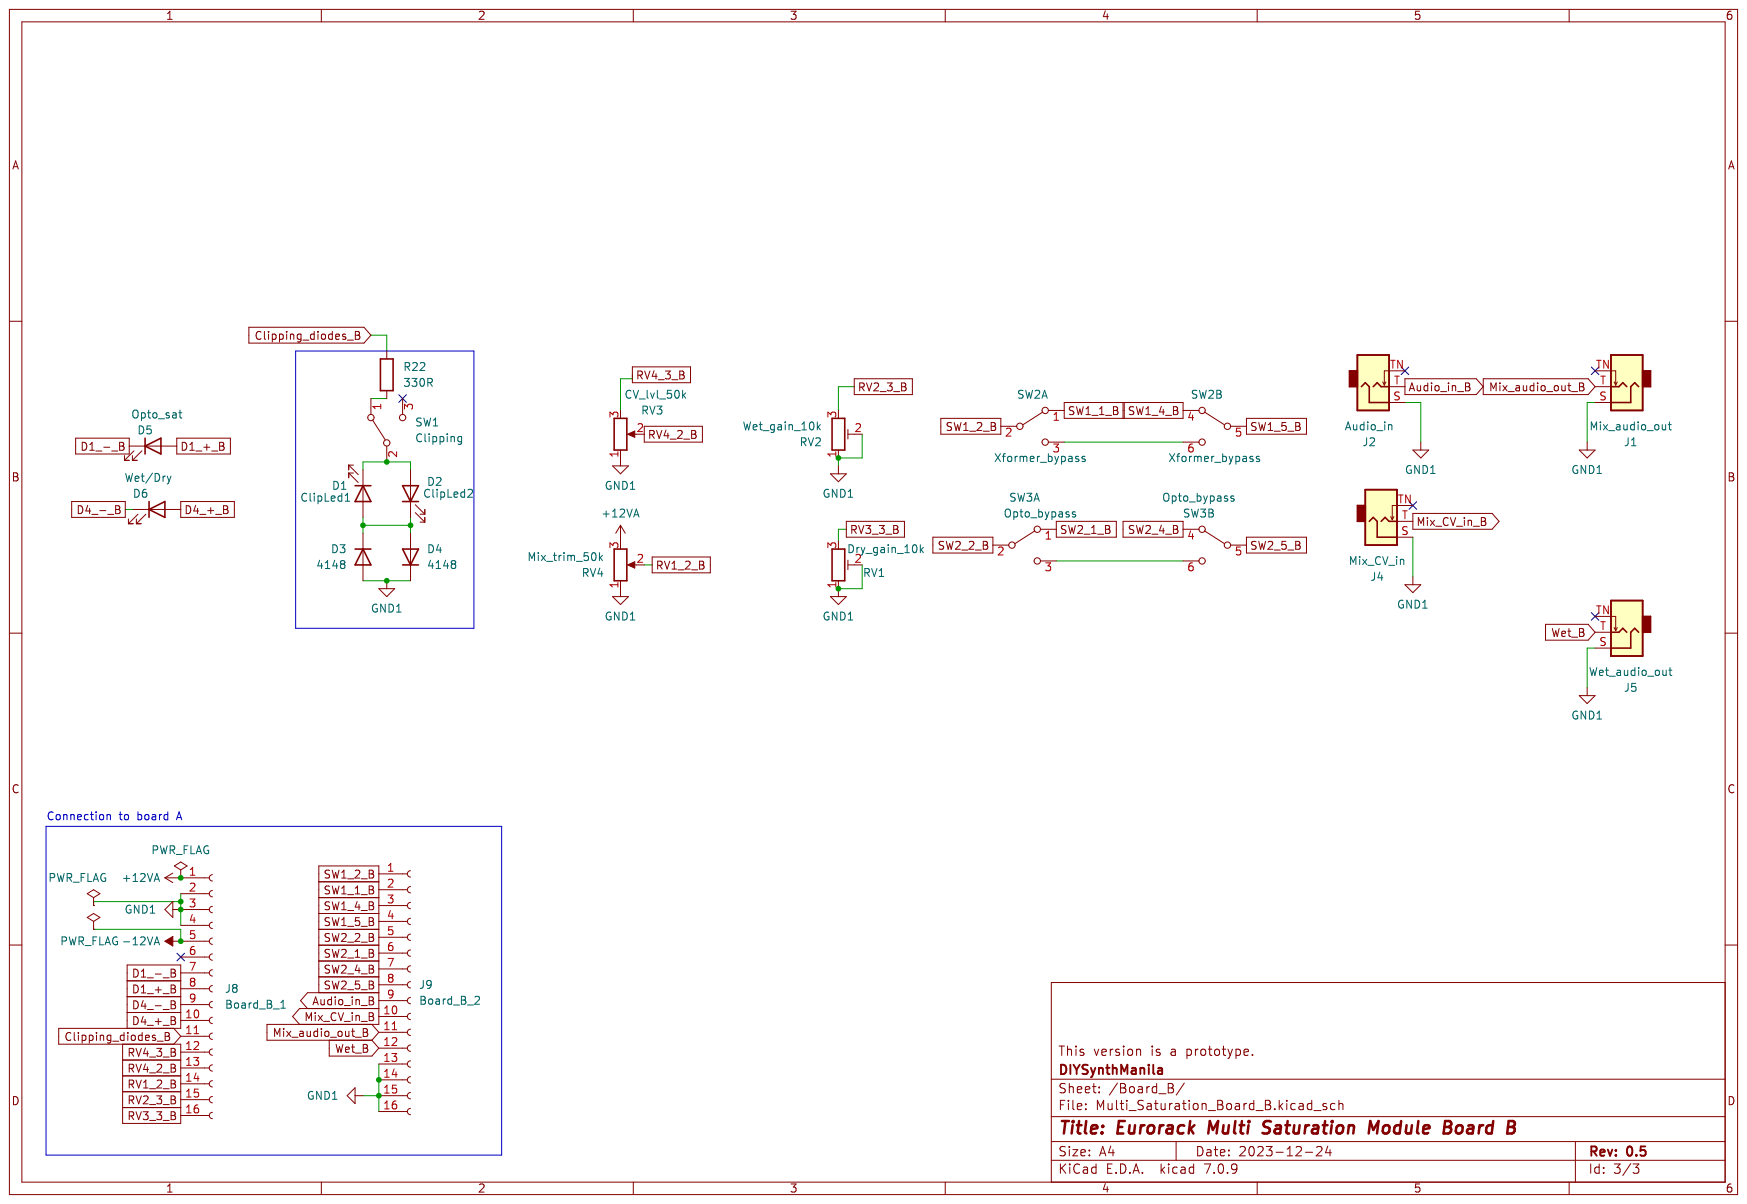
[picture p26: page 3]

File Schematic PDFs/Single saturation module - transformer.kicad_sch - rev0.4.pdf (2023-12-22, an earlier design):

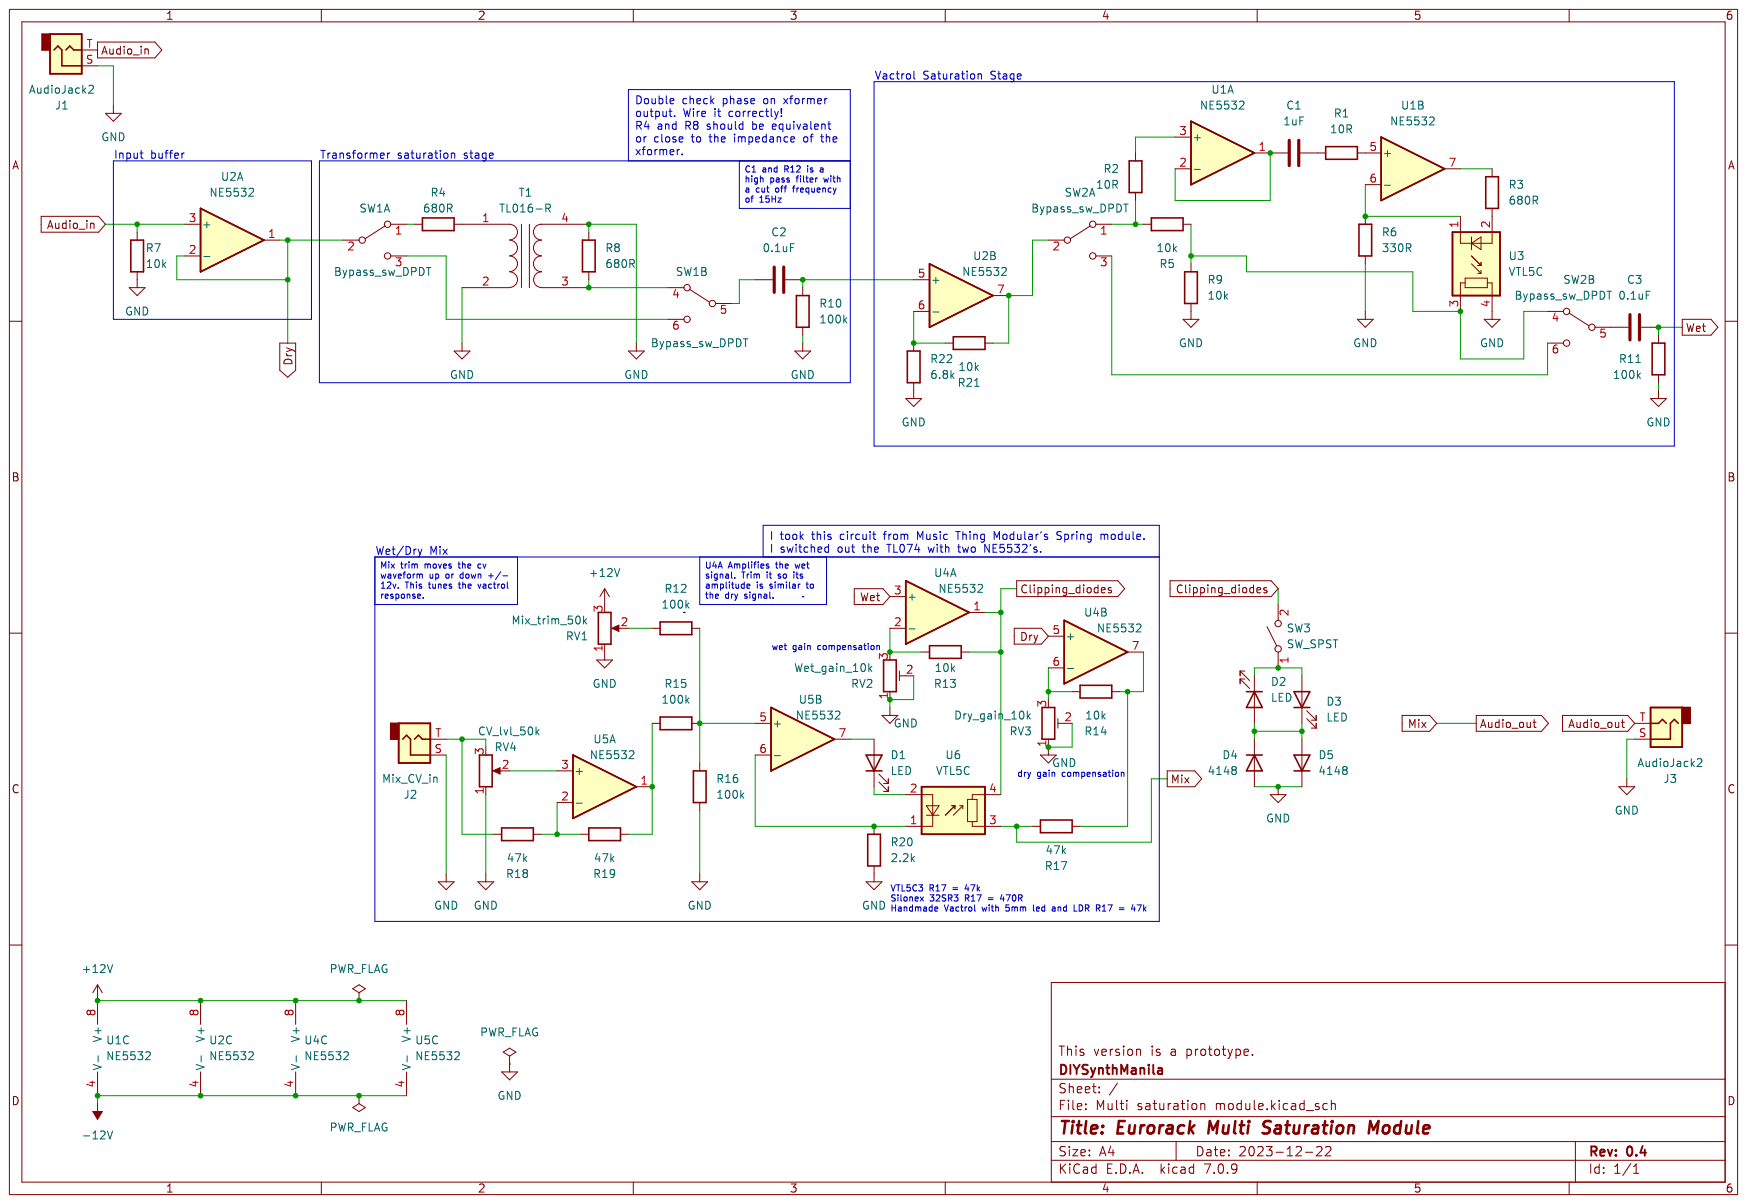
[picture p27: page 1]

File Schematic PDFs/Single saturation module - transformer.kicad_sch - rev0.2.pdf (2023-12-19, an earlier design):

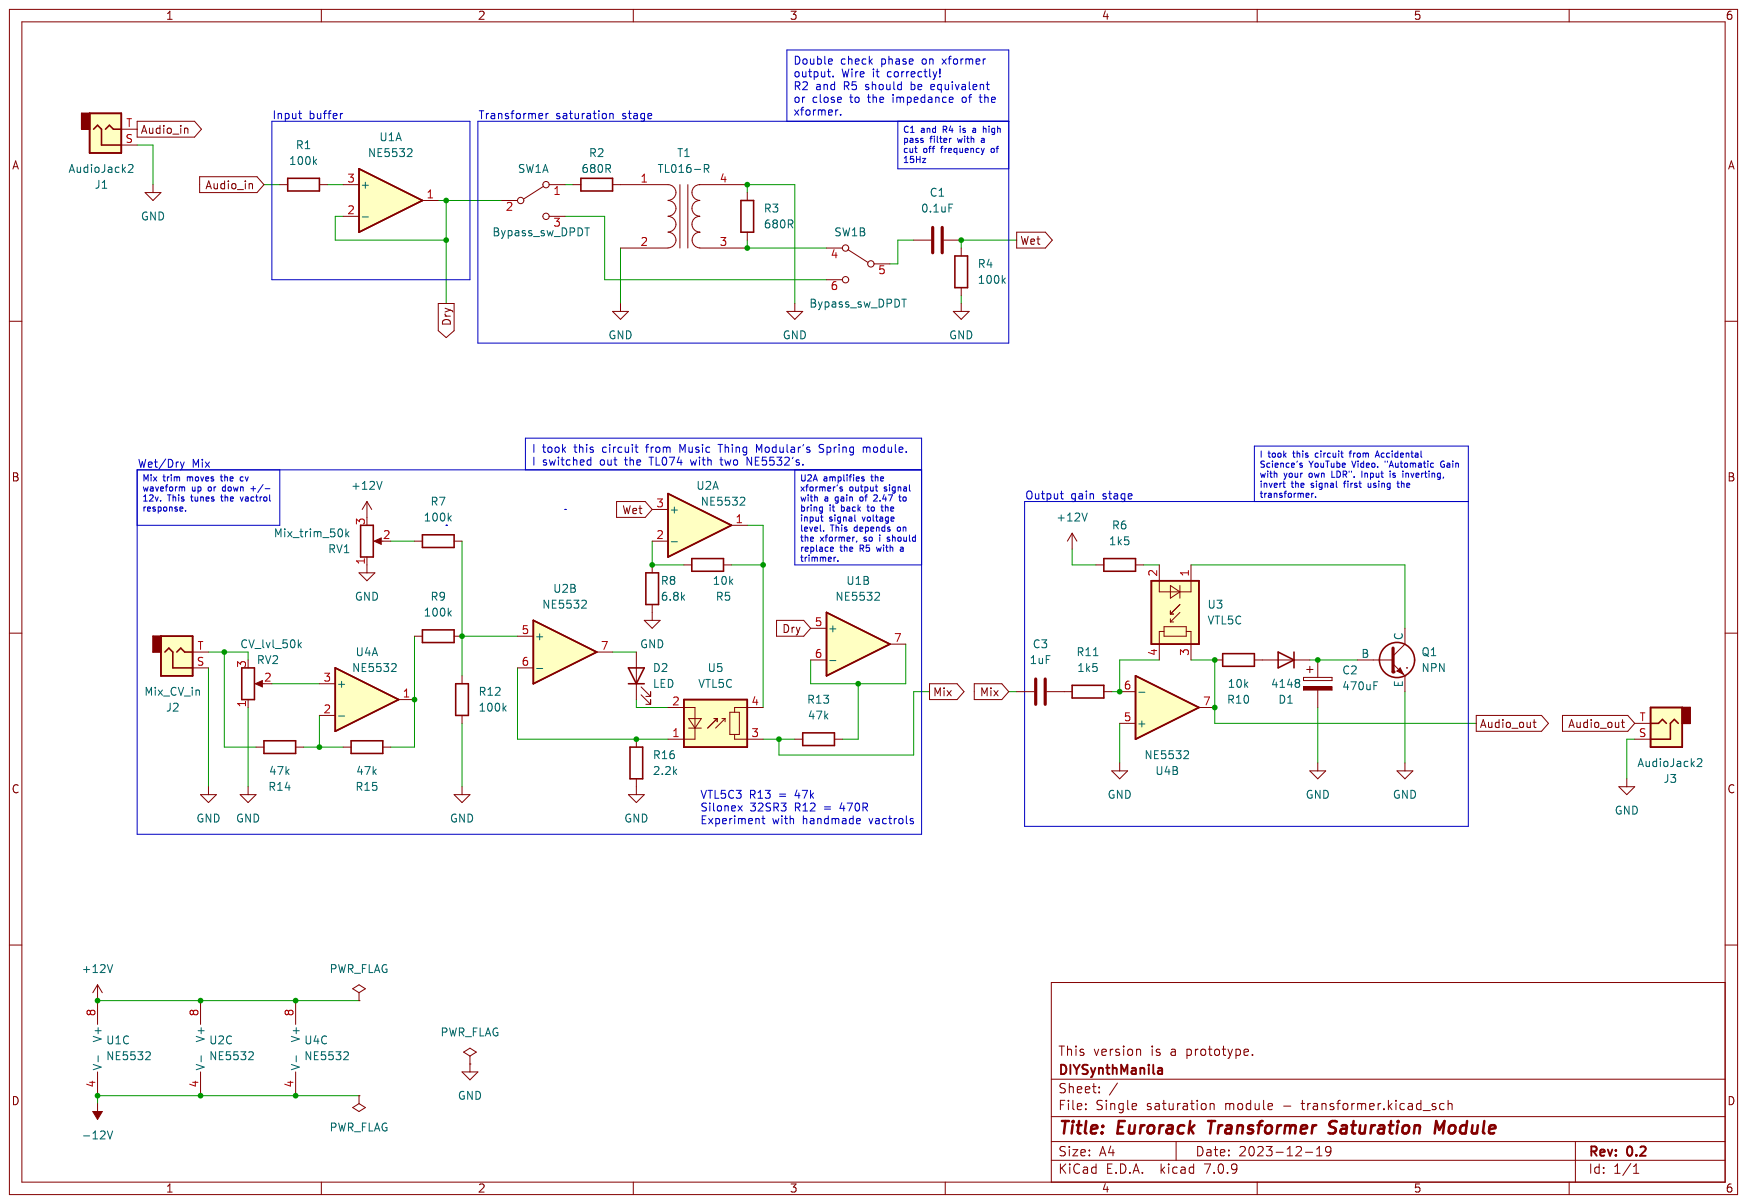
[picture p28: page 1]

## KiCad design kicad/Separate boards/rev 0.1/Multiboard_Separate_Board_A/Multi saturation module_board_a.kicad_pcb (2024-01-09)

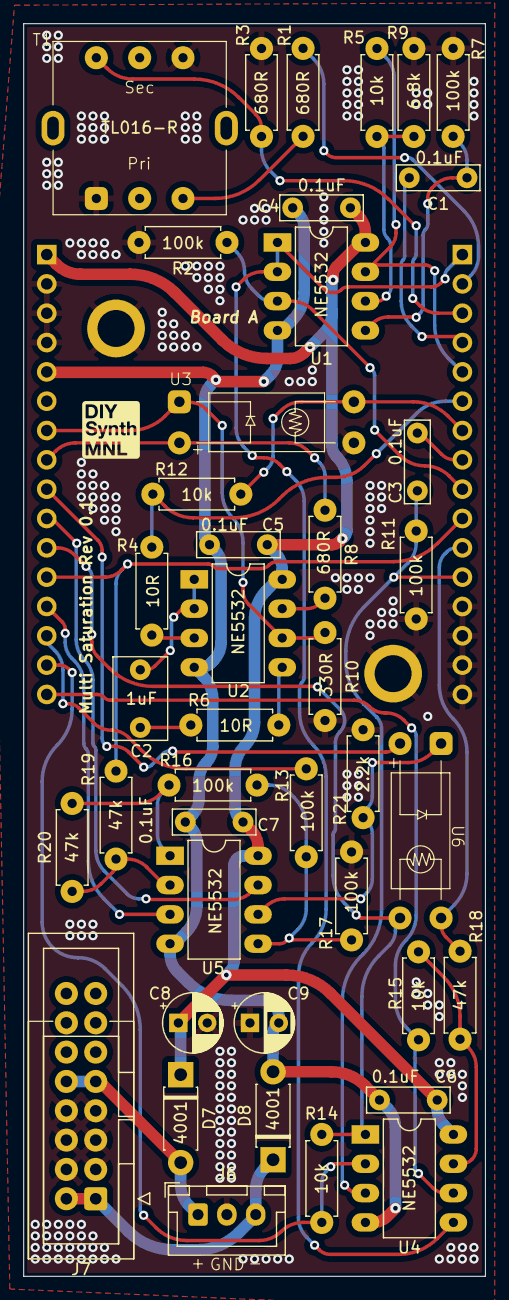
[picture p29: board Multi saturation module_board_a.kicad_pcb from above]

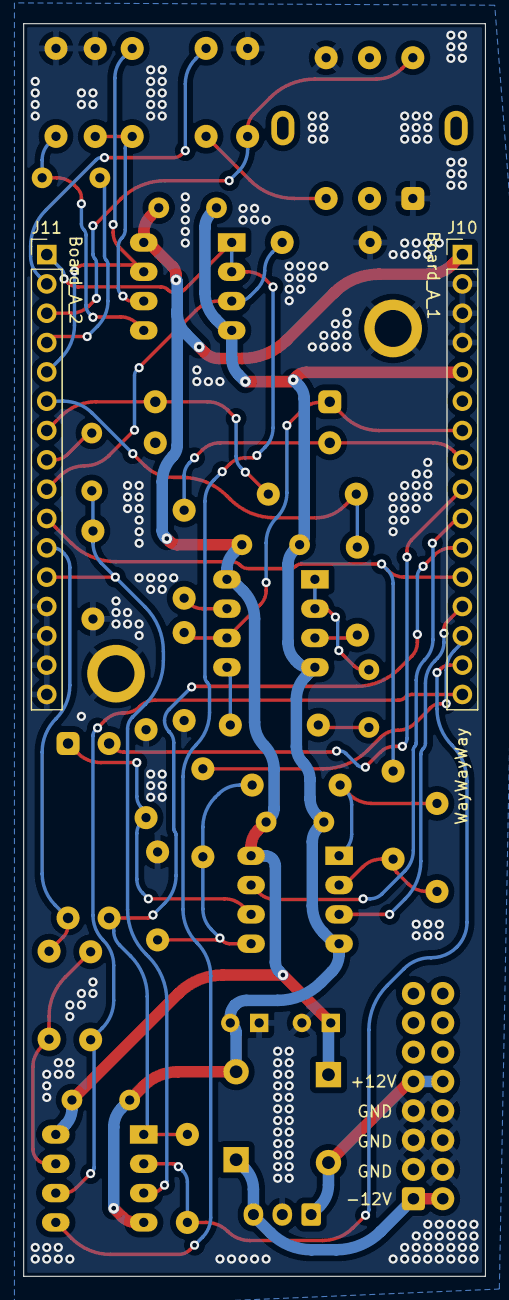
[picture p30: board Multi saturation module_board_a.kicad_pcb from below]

Board: 2 copper layers, 40.0 x 108.5 mm, 46 parts (2 on the bottom side), 39 nets.

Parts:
B1: Board
C1, C3, C4, C5, C6, C7: 0.1uF; C_Rect_L7.0mm_W2.0mm_P5.00mm_BigPads
C2: 1uF; C_Rect_L7.0mm_W4.5mm_P5.00mm_BigPads
C8, C9: 22uF; CP_Radial_D5.0mm_P2.50mm
D7, D8: 4001; D_DO-41_SOD81_P7.62mm_Horizontal_BigPads
H1, H2: MountingHole; MountingHole_M3_Standoff_Pad
J6: EuroPower_JST_3P; Eurorack_power_jst_3P
J7: EURO_PWR_16P; IDC-Header_2x08_P2.54mm_Vertical
J10: Board_A_1; PinHeader_1x16_P2.54mm_Vertical
J11: Board_A_2; PinHeader_1x16_P2.54mm_Vertical
R1, R3, R8: 680R; R_quarter_watt_L6.3mm_D2.5mm_P7.62mm
R2, R7, R11, R13, R16, R17: 100k; R_quarter_watt_L6.3mm_D2.5mm_P7.62mm
R4, R6: 10R; R_quarter_watt_L6.3mm_D2.5mm_P7.62mm
R5, R12, R14, R15: 10k; R_quarter_watt_L6.3mm_D2.5mm_P7.62mm
R9: 6.8k; R_quarter_watt_L6.3mm_D2.5mm_P7.62mm
R10: 330R; R_quarter_watt_L6.3mm_D2.5mm_P7.62mm
R18, R19, R20: 47k; R_quarter_watt_L6.3mm_D2.5mm_P7.62mm
R21: 2.2k; R_quarter_watt_L6.3mm_D2.5mm_P7.62mm
T1: TL016-R; Audio_transformer_TL016-R
U1, U2, U4, U5: NE5532; DIP-8_W7.62mm_LongPads
U3, U6: VTL5C; Handmade_vactrol_5mm

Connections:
Board_0-+12V: C4.1, C5.1, C6.1, C7.1, C8.1, D7.1 (K), J10.1, U1.8 (V+), U2.8 (V+), U4.8 (V+), U5.8 (V+)
Board_0--12V: C4.2, C5.2, C6.2, C7.2, C9.2, D8.2 (A), J10.5, U1.4 (V-), U2.4 (V-), U4.4 (V-), U5.4 (V-)
Board_0-/Board_A/+12V_IN: D7.2 (A), J6.1 (+12v), J7.9 (+12V), J7.10 (+12V)
Board_0-/Board_A/-12V_IN: D8.1 (K), J6.3 (-12v), J7.1 (-12V), J7.2 (-12V)
Board_0-Audio_in: J11.9, R2.1, U1.3 (+)
Board_0-Clipping_diodes: J10.11, R14.1, U4.1, U6.4
Board_0-D1_+: J10.8, R8.1, U3.2 (+)
Board_0-D1_-: J10.7, R10.1, U2.6 (-), U3.1 (-)
Board_0-D4_+: J10.10, U5.7
Board_0-D4_-: J10.9, U6.2 (+)
Board_0-Dry: J11.1, U1.1, U1.2 (-), U4.5 (+)
Board_0-GND: C8.2, C9.1, H1.1, H2.1, J6.2 (GND), J7.3 (GND), J7.4 (GND), J7.5 (GND), J7.6 (GND), J7.7 (GND), J7.8 (GND), J10.2, J10.3, J10.4, J11.13, J11.14, J11.15, J11.16, R2.2, R3.1, R7.2, R9.2, R10.2, R11.2, R17.2, R21.2, T1.1, T1.4, U3.4
Board_0-Mix_CV_in: J10.12, J11.10, R19.1
Board_0-Mix_audio_out: J11.11, R18.1, U6.3
Board_0-Net-(C2-Pad2): C2.2, R6.1
Board_0-Net-(R1-Pad2): R1.2, T1.3
Board_0-Net-(R8-Pad2): R8.2, U2.7
Board_0-Net-(R15-Pad1): R15.1, R18.2, U4.7
Board_0-Net-(R16-Pad2): R16.2, R20.2, U5.1
Board_0-Net-(U1B-+): C1.1, R7.1, U1.5 (+)
Board_0-Net-(U1B--): R5.1, R9.1, U1.6 (-)
Board_0-Net-(U2A-+): R4.2, U2.3 (+)
Board_0-Net-(U2A--): C2.1, U2.1, U2.2 (-)
Board_0-Net-(U2B-+): R6.2, U2.5 (+)
Board_0-Net-(U5A--): R19.2, R20.1, U5.2 (-)
Board_0-Net-(U5B-+): R13.2, R16.1, R17.1, U5.5 (+)
Board_0-Net-(U5B--): R21.1, U5.6 (-), U6.1 (-)
Board_0-RV1_2: J10.14, R13.1
Board_0-RV2_3: J10.15, R14.2, U4.2 (-)
Board_0-RV3_3: J10.16, R15.2, U4.6 (-)
Board_0-RV4_2: J10.13, U5.3 (+)
Board_0-SW1_1: J11.2, R1.1
Board_0-SW1_4: J11.3, R3.2, T1.6
Board_0-SW1_5: C1.2, J11.4
Board_0-SW2_1: J11.6, R4.1, R12.2
Board_0-SW2_2: J11.5, R5.2, U1.7
Board_0-SW2_4: J11.7, R12.1, U3.3
Board_0-SW2_5: C3.2, J11.8
Board_0-Wet: C3.1, J11.12, R11.1, U4.3 (+)

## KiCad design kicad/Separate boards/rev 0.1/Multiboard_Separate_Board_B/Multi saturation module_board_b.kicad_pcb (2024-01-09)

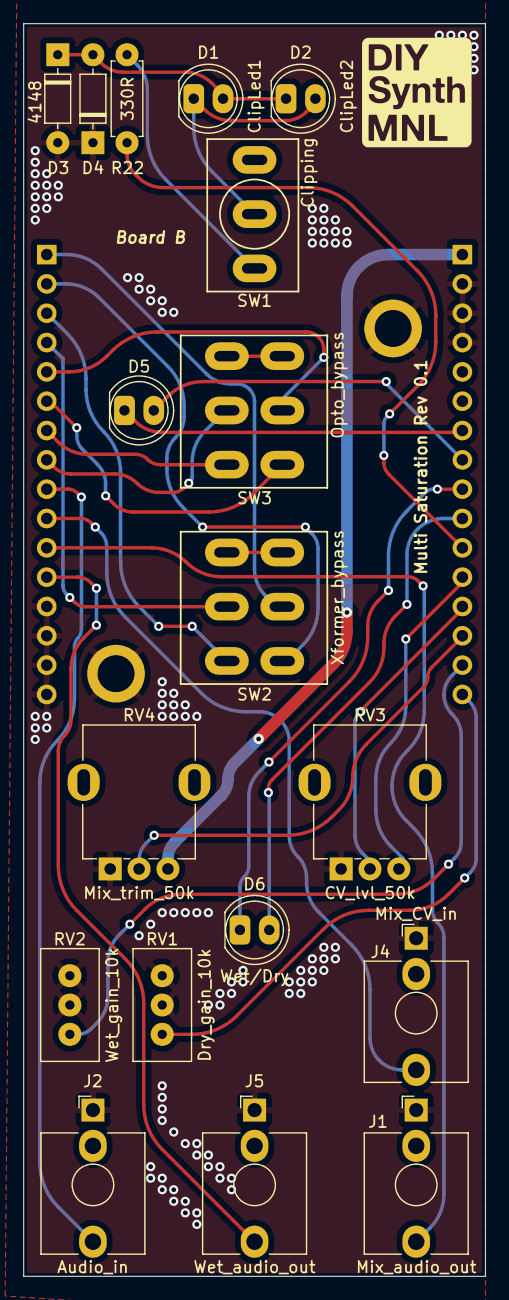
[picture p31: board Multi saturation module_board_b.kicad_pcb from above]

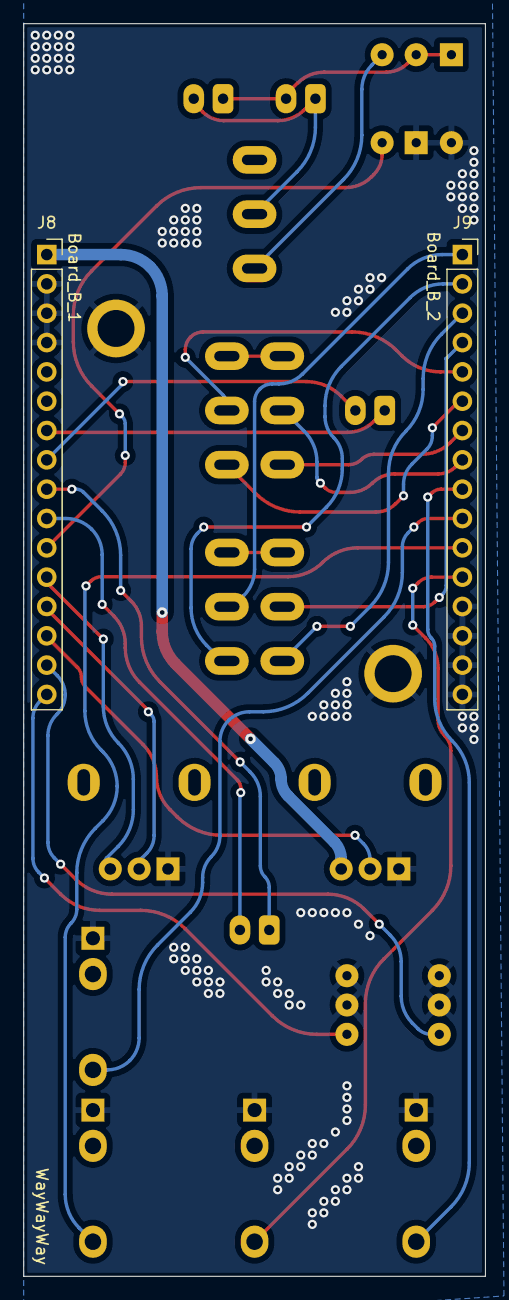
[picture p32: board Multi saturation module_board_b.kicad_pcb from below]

Board: 2 copper layers, 40.0 x 108.5 mm, 23 parts (2 on the bottom side), 29 nets.

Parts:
B2: Board
D1: ClipLed1; LED_D5.0mm_BigPads
D2: ClipLed2; LED_D5.0mm_BigPads
D3, D4: 4148; D_4148_BigPads
D5: Opto_sat; LED_D5.0mm_BigPads
D6: Wet/Dry; LED_D5.0mm_BigPads
H3, H4: MountingHole; MountingHole_M3_Standoff_Pad
J1: Mix_audio_out; AudioJack_3.5mm_long_pads
J2: Audio_in; AudioJack_3.5mm_long_pads
J4: Mix_CV_in; AudioJack_3.5mm_long_pads
J5: Wet_audio_out; AudioJack_3.5mm_long_pads
J8: Board_B_1; PinSocket_1x16_P2.54mm_Vertical
J9: Board_B_2; PinSocket_1x16_P2.54mm_Vertical
R22: 330R; R_quarter_watt_L6.3mm_D2.5mm_P7.62mm
RV1: Dry_gain_10k; Potentiometer_Bourns_3296W_Vertical_BigPads
RV2: Wet_gain_10k; Potentiometer_Bourns_3296W_Vertical_BigPads
RV3: CV_lvl_50k; Potentiometer_RV09_BigPads
RV4: Mix_trim_50k; Potentiometer_RV09_BigPads
SW1: Clipping; ToggleSwitch_MTS-102_SPDT
SW2: Xformer_bypass; ToggleSwitch_MTS-202_DPDT
SW3: Opto_bypass; ToggleSwitch_MTS-202_DPDT

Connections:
Board_0-+12VA: J8.1, RV4.3
Board_0-Audio_in_B: J2.T, J9.9
Board_0-Clipping_diodes_B: J8.11, R22.2
Board_0-D1_+_B: D5.2 (A), J8.8
Board_0-D1_-_B: D5.1 (K), J8.7
Board_0-D4_+_B: D6.2 (A), J8.10
Board_0-D4_-_B: D6.1 (K), J8.9
Board_0-GND1: D3.2 (A), D4.1 (K), H3.1, H4.1, J1.S, J2.S, J4.S, J5.S, J8.2, J8.3, J8.4, J9.13, J9.14, J9.15, J9.16, RV1.1, RV1.2, RV2.1, RV2.2, RV3.1, RV4.1
Board_0-Mix_CV_in_B: J4.T, J9.10
Board_0-Mix_audio_out_B: J1.T, J9.11
Board_0-Net-(D1-A): D1.2 (A), D2.1 (K), D3.1 (K), D4.2 (A)
Board_0-Net-(D1-K): D1.1 (K), D2.2 (A), SW1.2 (B)
Board_0-Net-(SW1-A): R22.1, SW1.1 (A)
Board_0-Net-(SW2A-C): SW2.3 (C), SW2.6 (C)
Board_0-Net-(SW3A-C): SW3.3 (C), SW3.6 (C)
Board_0-RV1_2_B: J8.14, RV4.2
Board_0-RV2_3_B: J8.15, RV2.3
Board_0-RV3_3_B: J8.16, RV1.3
Board_0-RV4_2_B: J8.13, RV3.2
Board_0-RV4_3_B: J8.12, RV3.3
Board_0-SW1_1_B: J9.2, SW2.1 (A)
Board_0-SW1_2_B: J9.1, SW2.2 (B)
Board_0-SW1_4_B: J9.3, SW2.4 (A)
Board_0-SW1_5_B: J9.4, SW2.5 (B)
Board_0-SW2_1_B: J9.6, SW3.1 (A)
Board_0-SW2_2_B: J9.5, SW3.2 (B)
Board_0-SW2_4_B: J9.7, SW3.4 (A)
Board_0-SW2_5_B: J9.8, SW3.5 (B)
Board_0-Wet_B: J5.T, J9.12

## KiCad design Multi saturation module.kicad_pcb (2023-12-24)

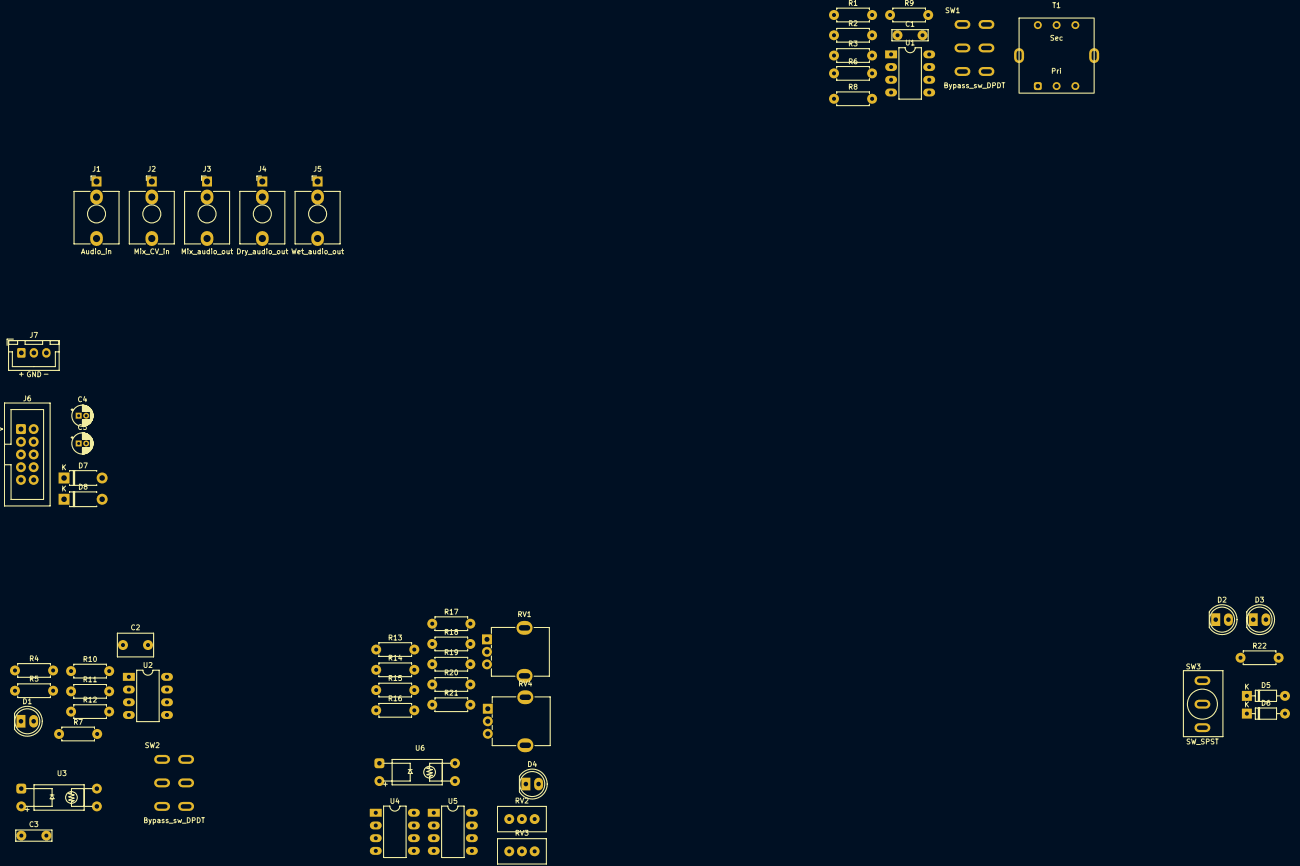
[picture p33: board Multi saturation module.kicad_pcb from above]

Board: 2 copper layers, 56 parts (0 on the bottom side), 44 nets, no tracks yet.

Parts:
C1, C3: 0.1uF; C_Rect_L7.0mm_W2.0mm_P5.00mm_BigPads
C2: 1uF; C_Rect_L7.0mm_W4.5mm_P5.00mm_BigPads
C4, C5: 22uF; CP_Radial_D4.0mm_P1.50mm
D1, D2, D3, D4: LED; LED_D5.0mm_BigPads
D5, D6: 4148; D_4148_BigPads
D7, D8: 4001; D_DO-41_SOD81_P7.62mm_Horizontal_BigPads
J1: Audio_in; AudioJack_3.5mm_long_pads
J2: Mix_CV_in; AudioJack_3.5mm_long_pads
J3: Mix_audio_out; AudioJack_3.5mm_long_pads
J4: Dry_audio_out; AudioJack_3.5mm_long_pads
J5: Wet_audio_out; AudioJack_3.5mm_long_pads
J6: EURO_PWR_2x5; IDC-Header_2x05_P2.54mm_Vertical_BigPads
J7: EuroPower_JST_3P; Eurorack_power_jst_3P
R1, R3, R7: 680R; R_quarter_watt_L6.3mm_D2.5mm_P7.62mm
R2, R6, R11, R13, R16, R17: 100k; R_quarter_watt_L6.3mm_D2.5mm_P7.62mm
R4, R5: 10R; R_quarter_watt_L6.3mm_D2.5mm_P7.62mm
R8, R12, R14, R15: 10k; R_quarter_watt_L6.3mm_D2.5mm_P7.62mm
R9: 6.8k; R_quarter_watt_L6.3mm_D2.5mm_P7.62mm
R10, R22: 330R; R_quarter_watt_L6.3mm_D2.5mm_P7.62mm
R18, R19, R20: 47k; R_quarter_watt_L6.3mm_D2.5mm_P7.62mm
R21: 2.2k; R_quarter_watt_L6.3mm_D2.5mm_P7.62mm
RV1: Mix_trim_50k; Potentiometer_RV09_BigPads
RV2: Wet_gain_10k; Potentiometer_Bourns_3296W_Vertical_BigPads
RV3: Dry_gain_10k; Potentiometer_Bourns_3296W_Vertical_BigPads
RV4: CV_lvl_50k; Potentiometer_RV09_BigPads
SW1, SW2: Bypass_sw_DPDT; ToggleSwitch_MTS-202_DPDT
SW3: SW_SPST; ToggleSwitch_MTS-102_SPDT
T1: TL016-R; Audio_transformer_TL016-R
U1, U2, U4, U5: NE5532; DIP-8_W7.62mm_LongPads
U3, U6: VTL5C; Handmade_vactrol_5mm

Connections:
+12V: C4.1, D7.1 (K), RV1.3, U1.8 (V+), U2.8 (V+), U4.8 (V+), U5.8 (V+)
-12V: C5.2, D8.2 (A), U1.4 (V-), U2.4 (V-), U4.4 (V-), U5.4 (V-)
Audio_in: J1.T, R2.1, U1.3 (+)
Clipping_diodes: R14.1, R22.2, U4.1, U6.4
Dry: J4.T, SW1.2 (B), U1.1, U1.2 (-), U4.5 (+)
GND: C4.2, C5.1, D5.2 (A), D6.1 (K), J1.S, J2.S, J3.S, J4.S, J5.S, J6.3 (GND), J6.4 (GND), J6.5 (GND), J6.6 (GND), J6.7 (GND), J6.8 (GND), J7.2 (GND), R2.2, R3.1, R6.2, R9.2, R10.2, R11.2, R17.2, R21.2, RV1.1, RV2.1, RV2.2, RV3.1, RV3.2, RV4.1, T1.1, T1.4, U3.4
Mix_CV_in: J2.T, R19.1, RV4.3
Mix_audio_out: J3.T, R18.1, U6.3
unnamed: C2.2, R5.1
unnamed: D1.2 (A), R7.1, U3.2 (+)
unnamed: D1.1 (K), R10.1, U2.6 (-), U3.1 (-)
unnamed: D2.2 (A), D3.1 (K), D5.1 (K), D6.2 (A)
unnamed: D2.1 (K), D3.2 (A), SW3.2 (B)
unnamed: D4.2 (A), U5.7
unnamed: D4.1 (K), U6.2 (+)
unnamed: D7.2 (A), J6.1 (+12V), J6.2 (+12V), J7.1 (+12v)
unnamed: D8.1 (K), J6.9 (-12V), J6.10 (-12V), J7.3 (-12v)
unnamed: R1.2, T1.3
unnamed: R7.2, U2.7
unnamed: R13.1, RV1.2
unnamed: R15.1, R18.2, U4.7
unnamed: R16.2, R20.2, U5.1
unnamed: R1.1, SW1.1 (A)
unnamed: SW1.3 (C), SW1.6 (C)
unnamed: R3.2, SW1.4 (A), T1.6
unnamed: C1.2, SW1.5 (B)
unnamed: R4.1, R12.2, SW2.1 (A)
unnamed: R8.2, SW2.2 (B), U1.7
unnamed: SW2.3 (C), SW2.6 (C)
unnamed: R12.1, SW2.4 (A), U3.3
unnamed: C3.2, SW2.5 (B)
unnamed: R22.1, SW3.1 (A)
unnamed: C1.1, R6.1, U1.5 (+)
unnamed: R8.1, R9.1, U1.6 (-)
unnamed: R4.2, U2.3 (+)
unnamed: C2.1, U2.1, U2.2 (-)
unnamed: R5.2, U2.5 (+)
unnamed: R14.2, RV2.3, U4.2 (-)
unnamed: R15.2, RV3.3, U4.6 (-)
unnamed: RV4.2, U5.3 (+)
unnamed: R19.2, R20.1, U5.2 (-)
unnamed: R13.2, R16.1, R17.1, U5.5 (+)
unnamed: R21.1, U5.6 (-), U6.1 (-)
Wet: C3.1, J5.T, R11.1, U4.3 (+)

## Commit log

2023-12-20 version 0.3 update
    [Single saturation module - transformer.kicad_sch]
2023-12-21 version 0.3 readme update
    [Single saturation module - transformer.kicad_sch]
2023-12-21 renamed the project
    [Multi saturation module.kicad_pcb, Multi saturation module.kicad_sch]
2023-12-22 revision 0.4
    [Multi saturation module.kicad_sch]
2023-12-23 revision 0.4 update
    [Multi saturation module.kicad_sch]
2023-12-24 rev 0.5 update
    [Multi saturation module.kicad_sch]
2023-12-24 Revision 5 update
    This commit is before I separate the schematic parts into boards.
    [Multi saturation module.kicad_pcb, Multi saturation module.kicad_sch]
2023-12-24 Separate boards branch started
    [Multi saturation module.kicad_pcb, Multi saturation module.kicad_sch]
2023-12-25 Laid out footprints on three boards
    [Multi saturation module.kicad_pcb, Multi saturation module.kicad_sch, Multi_Saturation_Board_A.kicad_sch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]
2023-12-25 board update
    [Multi saturation module.kicad_pcb, Multi_Saturation_Board_A.kicad_sch, Multi_Saturation_Board_B.kicad_sch]
2023-12-25 All boards routed
    [Multi saturation module.kicad_pcb, Multi_Saturation_Board_A.kicad_sch, Multi_Saturation_Board_B.kicad_sch]
2023-12-25 board routing update
    [Multi saturation module.kicad_pcb]
2023-12-25 routing with bigger traces finished
    [Multi saturation module.kicad_pcb]
2023-12-25 board connector wrong placement fix
    [Multi saturation module.kicad_pcb]
2023-12-28 added rev 0.5 and 0.6 schematic pdfs
2023-12-28 cleaned up project directory
    [Multi saturation module.kicad_sch, MultiSaturation_3D_Model.FCStd, MultiSaturation_FPANEL.dxf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]
2023-12-28 Added pcb sheet details
2023-12-29 board and schematic update
    [Multi_Saturation_Board_A.kicad_sch, Multi_Saturation_Board_B.kicad_sch]
2023-12-30 Kikit Multiboard to single board excecuted for all boards
    [Multi saturation module_board_a.kicad_pcb, Multi saturation module_board_b.kicad_pcb]
2024-01-05 multiboard update, rounded tracks
    [Multi saturation module_board_a.kicad_pcb, Multi saturation module_board_b.kicad_pcb]
2024-01-06 gerbers updated
2024-01-09 ibom and schematic update
2024-01-14 revision 0.2 started
    [Multi saturation module_board_a.kicad_pcb, Multi saturation module_board_b.kicad_pcb]
2024-01-22 added kicad gitignore
2026-05-14 Fix Build status link path case
2026-05-14 Add photos/ placeholder for assembled-module shots
2026-05-14 Add assembled-module photos and update README hero
2026-05-14 Add circuit walkthrough and calibration procedure to README
2026-05-14 Add references/ folder with archived DIYRe Colour schematics
    Local copies of the three borrowed sources cited in the README: CTX
    Cinemag mkII, Colourphone v1.3, and Colourupter v1.7. Originals are
    on diyrecordingequipment.com's CDN, which could go away.
